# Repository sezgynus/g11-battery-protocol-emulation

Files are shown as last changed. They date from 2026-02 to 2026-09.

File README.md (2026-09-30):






# Language Selection
[English](README-en.md) | [Türkçe](README.md)

# G11 Battery Protocol Emulation

## Projeye Genel Bakış

Bu proje, Xiaomi G11 akıllı bataryası ile süpürge arasındaki kapalı haberleşme protokolünün tersine mühendislik yöntemiyle analiz edilmesini, protokolün çözümlenmesini ve ESP32 üzerinde emüle edilmesini kapsar.

Amaç yalnızca veri hattını dinlemek değil; fiziksel katmandan paket yapısına, adresleme ve checksum mekanizmasından işlevsel payload alanlarına kadar sistemi yeniden uygulanabilecek seviyede karakterize etmekti. Elde edilen protokol ESP32 üzerinde uygulanmış ve orijinal süpürge elektroniği tarafından kabul edilen çalışan bir emülatör ile doğrulanmıştır.

### Sonuç

- Kapalı batarya haberleşme arayüzü elektriksel olarak karakterize edildi.
- Fiziksel katman **single-wire, half-duplex, inverted UART** olarak belirlendi.
- Haberleşme **9600 baud, 8N1** olarak çözüldü.
- Süpürgenin master/polling, bataryanın slave/response tarafı olduğu doğrulandı.
- Paket sınırları, source/target adresleme yapısı ve 16-bit toplamsal checksum çözüldü.
- Checksum algoritması yaklaşık **6500 paketlik** veri setinin tamamında doğrulandı.
- Üç temel paket tipinde toplam **29 / 37 byte (~%78)** karakterize edildi.
- Emülasyon için gerekli işlevsel alanlar belirlendi ve ESP32 tabanlı protokol emülatörü başarıyla çalıştırıldı.
- Batarya denetleyici donanımı ve fiziksel batarya kutusu tasarlandı.

## Protokole Hızlı Bakış

| Özellik | Sonuç |
|---|---|
| Topoloji | Single-wire |
| Duplex | Half-duplex |
| Kodlama | Inverted UART |
| UART | 9600 baud, 8N1 |
| Master | Süpürge |
| Slave | Batarya |
| Hat genliği | ~24–25 V |
| Süpürge → Batarya | 0xFB → 0xFC |
| Batarya → Süpürge | 0xFC → 0xFB |
| Veri bütünlüğü | 16-bit toplamsal checksum |
| Karakterize edilen alan | 29 / 37 byte (~%78) |
| Emülasyon platformu | ESP32 |

```text
Start | Source ID | Target ID | Payload ... | Checksum_L | Checksum_H | End
```

```text
checksum = SUM(data bytes) & 0xFFFF
```

Checksum; başlangıç/bitiş byte'ları ve checksum alanının kendisi hariç paket byte'larının toplamıdır ve little-endian olarak `Checksum_L`, `Checksum_H` sırasıyla taşınır.

### Bulguların Güven Düzeyi

| Düzey | Alanlar |
|---|---|
| Doğrulanmış | Paket sınırları, source/target ID, checksum, batarya seviyesi, şarj durumu, tetik durumu, motor aktif/deaktif durumu |
| Güçlü biçimde desteklenen | Güç tüketimi, motor komut hızı |
| Kısmen karakterize | Akım alanı; davranış korelasyonu güçlü ancak birimi kesin değil |
| Bilinmeyen | Testlerde değişmeyen veya emülasyon için gerekli olmayan payload byte'ları |

> Payload coverage byte sayısı üzerinden hesaplanmıştır. Bilinmeyen alanlara rağmen, gösterilen batarya emülasyonu için gerekli alanlar belirlenmiştir.

## Tersine Mühendislik Akışı

```text
Konnektör ve pin tespiti
        ↓
Elektriksel karakterizasyon
        ↓
Güvenli sinyal yakalama
        ↓
Fiziksel katman tespiti
        ↓
Paket sınırları ve adresleme
        ↓
Checksum doğrulama
        ↓
Kontrollü kullanım senaryosu
        ↓
Payload korelasyonu
        ↓
ESP32 protokol emülasyonu
```

Aşağıdaki bölümler sonuçlara hangi ölçüm, hipotez ve doğrulama adımlarıyla ulaşıldığını gösterir.

## Reverse Engineering Metodolojisi

Bu proje aşağıdaki deterministik mühendislik adımlarını takip etmiştir:

<details>
<summary><strong>1️⃣ Arayüz Karakterizasyonu</strong></summary>

Batarya paketi ve süpürge gövdesi açılmadan analiz yapılması hedeflenmiştir.
Bu nedenle konnektör pin fonksiyonları dolaylı ve müdahalesiz (non-invasive) yöntemlerle
tespit edilmiştir.

## Referans PCB Görselleri

Model yeni olduğu için teardown materyali sınırlıdır.

Yapılan araştırmalar sonucunda:

- Batarya PCB görüntüsüne bir video incelemesinde,
- Süpürge tarafındaki PCB görüntüsüne çevrim içi bir yedek parça platformunda

ulaşılmıştır.

> Batarya PCB’sinde pin fonksiyonlarına dair işaretleme bulunmamaktadır.  
> Süpürge tarafındaki PCB üzerinde konnektör pin isimleri etiketlenmiştir.

📌 Referans Görseller:

### Batarya PCB fotoğrafı

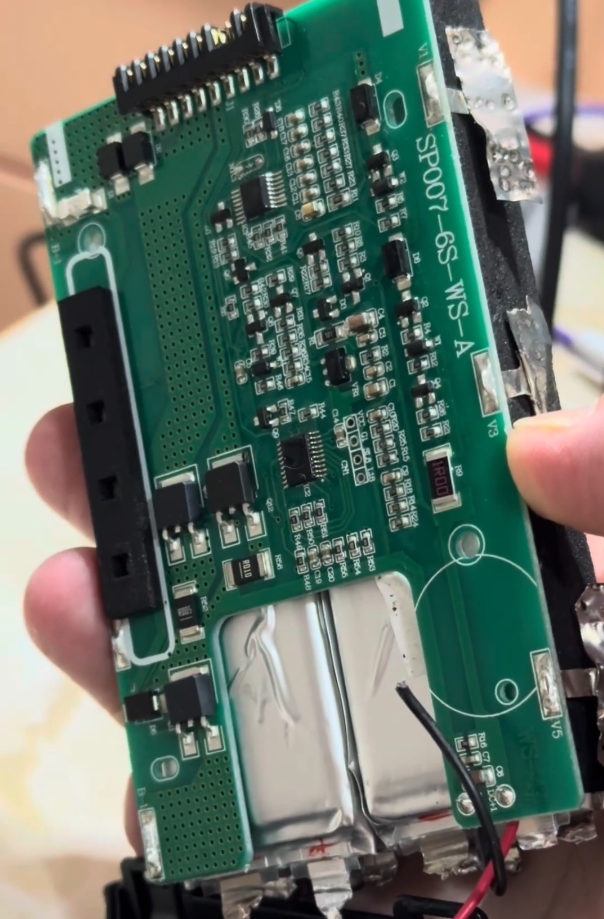
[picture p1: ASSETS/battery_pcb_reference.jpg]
Battery PCB Reference


### Süpürge PCB fotoğrafı

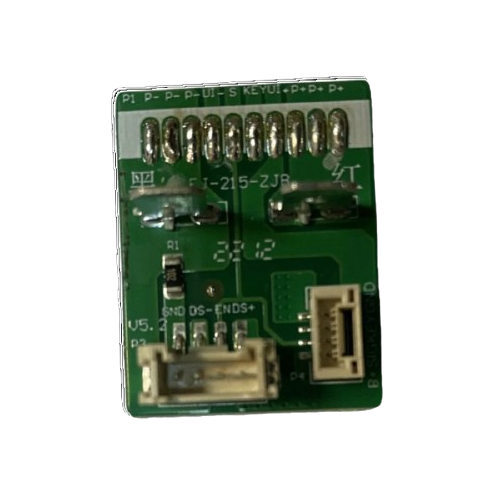
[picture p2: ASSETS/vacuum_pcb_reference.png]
Vacuum PCB Reference


---

## Konnektör Pin Dizilimi

10 pinli konnektör üzerinde yer alan pin isimleri:

P- | P- | P- | UI- | S | KEY | UI+ | P+ | P+ | P+

Ancak ilgili PCB'nin birebir aynı revizyona ait olduğu kesin olmadığı için
tüm pin fonksiyonları elektronik olarak doğrulanmıştır.

---

## Elektriksel Doğrulama

Batarya ve süpürge konnektörleri jumper kablolar ile açığa alınmış,
cihaz çalışırken ölçümler gerçekleştirilmiştir.

### Güç Hatları

- P- / P+ → Sürekli 24–25V DC  
  → Ana güç hattı olarak doğrulanmıştır.

### UI Hatları

- UI- / UI+ → Yalnızca ekran aktifken 24–25V  
  → Ekran besleme hattı olarak değerlendirilmiştir.

### KEY Hattı

- Tetik basılı → 24–25V  
- Tetik bırakıldığında → 0V  

→ Kullanıcı giriş hattı doğrulanmıştır.

### S Hattı

- Cihaz çalışırken → 24–25V genliğinde periyodik kare dalgalar  
- Cihaz kapalıyken → 0V sabit  

Bu davranış, hattın haberleşme hattı olduğunu güçlü şekilde göstermektedir.

---

### Pin Eşlemesinin Etiketlenmesi

Daha sonraki analiz çalışmalarında bağlantı hatalarını önlemek ve ölçüm
tekrar edilebilirliğini sağlamak amacıyla tespit edilen pin eşlemesi,
hem batarya hem de süpürge konnektörü üzerinde fiziksel olarak etiketlenmiştir.

Bu sayede:

- Ölçüm noktaları standardize edilmiştir.
- Yanlış bağlantı riski minimize edilmiştir.
- Veri yakalama aşamasında referans karışıklığı önlenmiştir.

### Etiketlenmiş Konnektör Görselleri

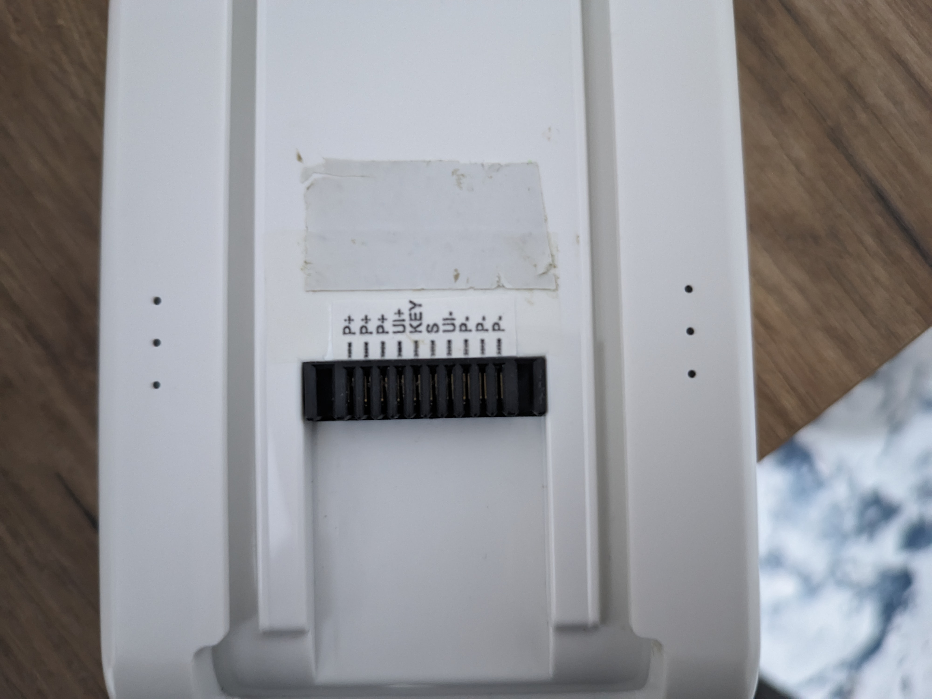
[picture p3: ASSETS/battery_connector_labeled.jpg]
Battery Connector Labeling
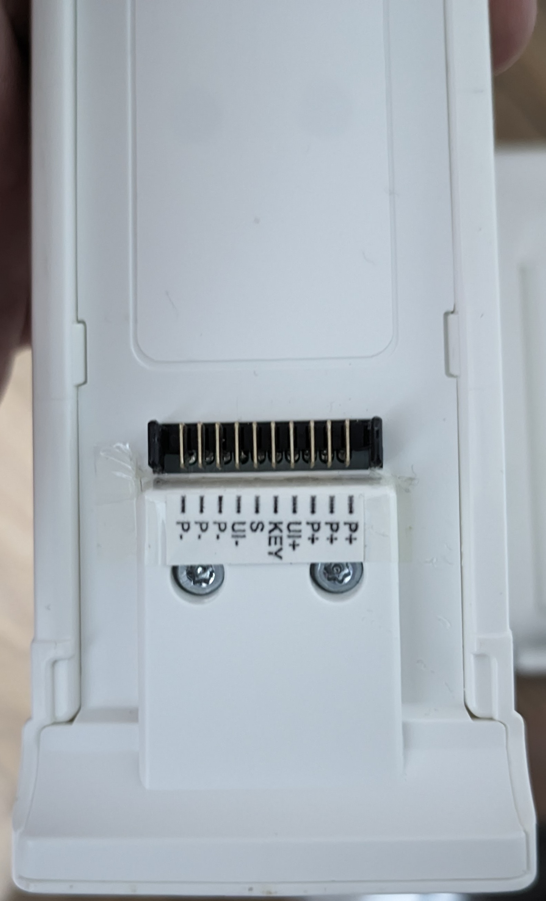
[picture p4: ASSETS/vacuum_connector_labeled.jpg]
Vacuum Connector Labeling
 

---

## Sonuç

- Güç hatları ayrıştırılmıştır.
- Kullanıcı giriş hattı doğrulanmıştır.
- Haberleşme hattı tespit edilmiştir.
- Sinyal genliği ~24–25V olarak ölçülmüştür.

Logic seviyesi 24V olduğu için doğrudan logic analyzer bağlantısı mümkün değildir.
Bir sonraki aşamada uygun level shifting çözümü gereklidir.
</details>
<details>
<summary><strong>2️⃣ Veri Yakalama ve Protokol Keşfi Denemeleri</strong></summary>

### Seviye Dönüştürücü (Level Shifter) Görselleri

#### 1. Delikli Pertinaks Üzerinde Yapılmış Devre
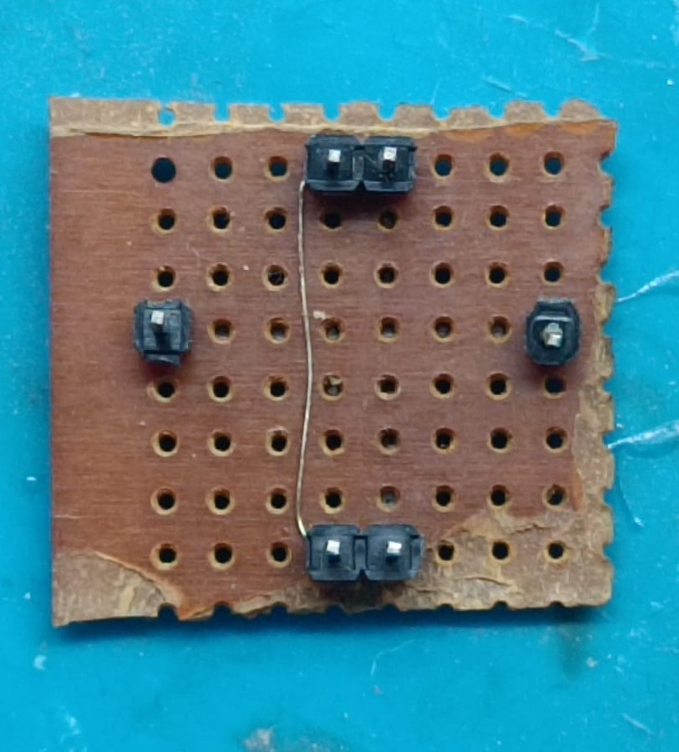
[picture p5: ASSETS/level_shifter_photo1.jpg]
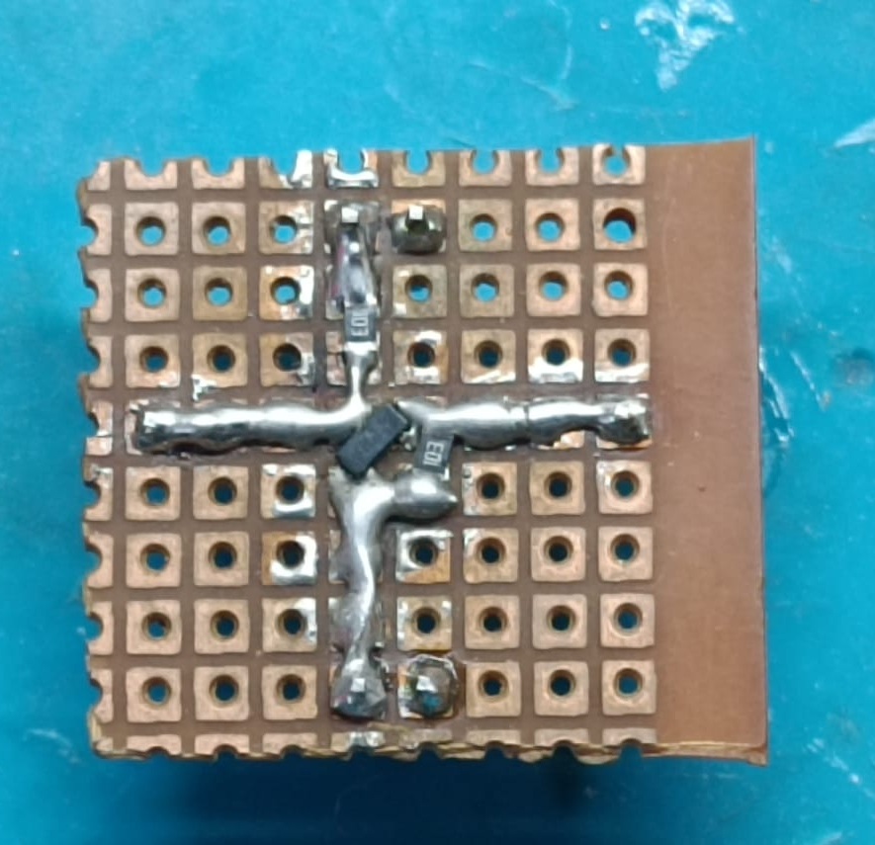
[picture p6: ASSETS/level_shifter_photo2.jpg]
 

#### 2. Şematik Görseli
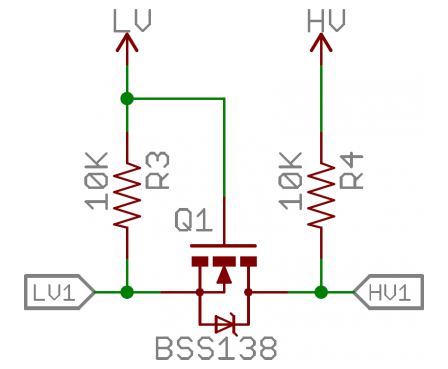
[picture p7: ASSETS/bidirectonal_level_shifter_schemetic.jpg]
Level Shifter Schematic


Batarya konnektörü ve level shifter devresi kurulduktan sonra
S hattından jumper alınıp lojik analizör girişine bağlanmıştır.  
Hattın güvenli şekilde dinlenmesi sağlanmıştır.

---

## İlk Analiz: 1-Wire Hipotezi

Hattın tek hatlı olması nedeniyle ilk olarak **1-Wire protokolü** varsayılmıştır.  

- Bazı anlamlı byte'lar gözlemlense de  
- Çok sayıda framing hatası ve korelasyonsuz byte dizileri mevcuttu  

Veri kaydı ve ekran görüntüleri:

[Capture Dosyası (Session 0.sal)](DOCUMENT/Session%200.sal)

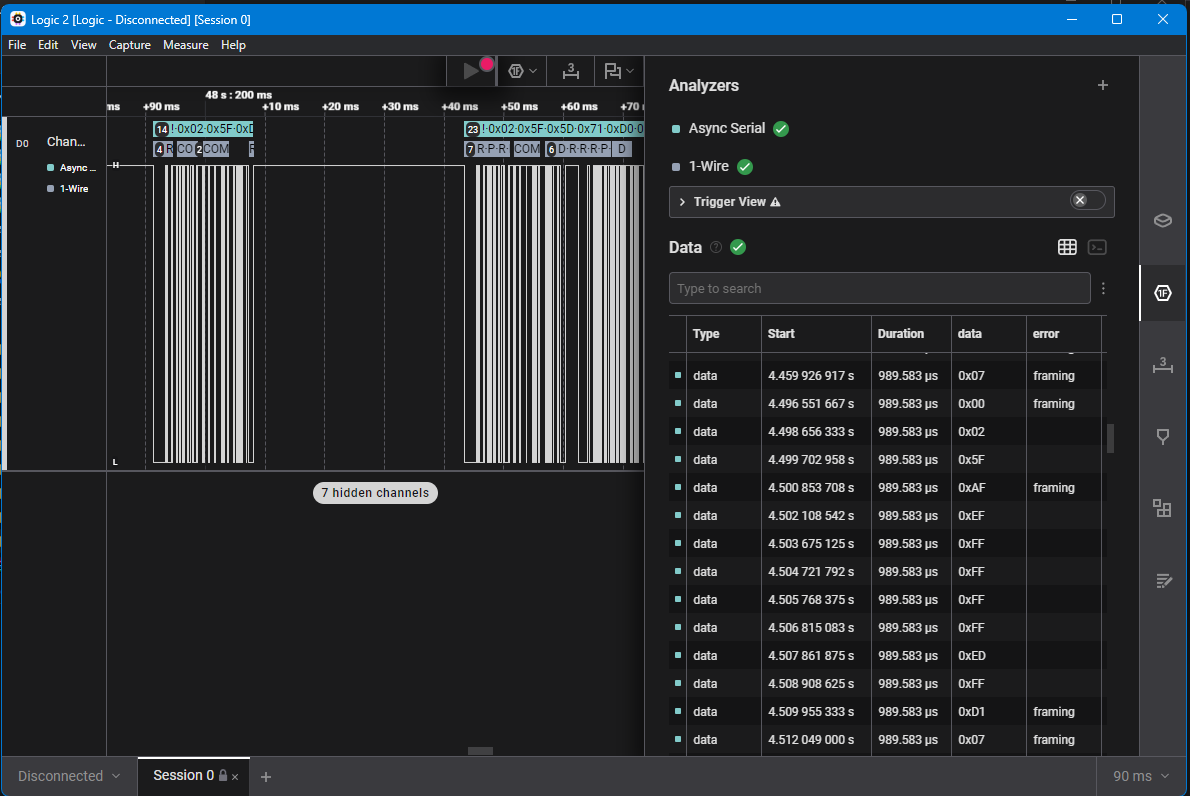
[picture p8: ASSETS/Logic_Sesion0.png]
Logic Analyzer Capture


Bu gözlemler, hattın **standart 1-Wire protokolü olmadığı** ihtimalini güçlendirdi.

---

## İkinci Analiz: Half-Duplex Single-Wire UART Hipotezi

Daha sonra hattın **half-duplex single-wire UART** olabileceği üzerine yoğunlaşıldı.  

- En yaygın standart baud hızlarında sinyal analiz edildi  
- Hâlâ çok sayıda çerçeveleme (framing) hatası vardı ve korelasyon gözlemlenmedi  

---

## Çözüm: Sinyalin Terslenmesi ve Doğru Parametreler

Son bir deneme olarak sinyal terslenerek analiz edildi ve:

- **8N1 standardı**  
- **9600 baud**  
- **Inverted signal**

parametreleriyle **çerçeveler (frame) tam olarak oturdu**.  

Veri kaydı ve ekran görüntüleri:

[Capture Dosyası (Session 1.sal)](DOCUMENT/Session%201.sal)  

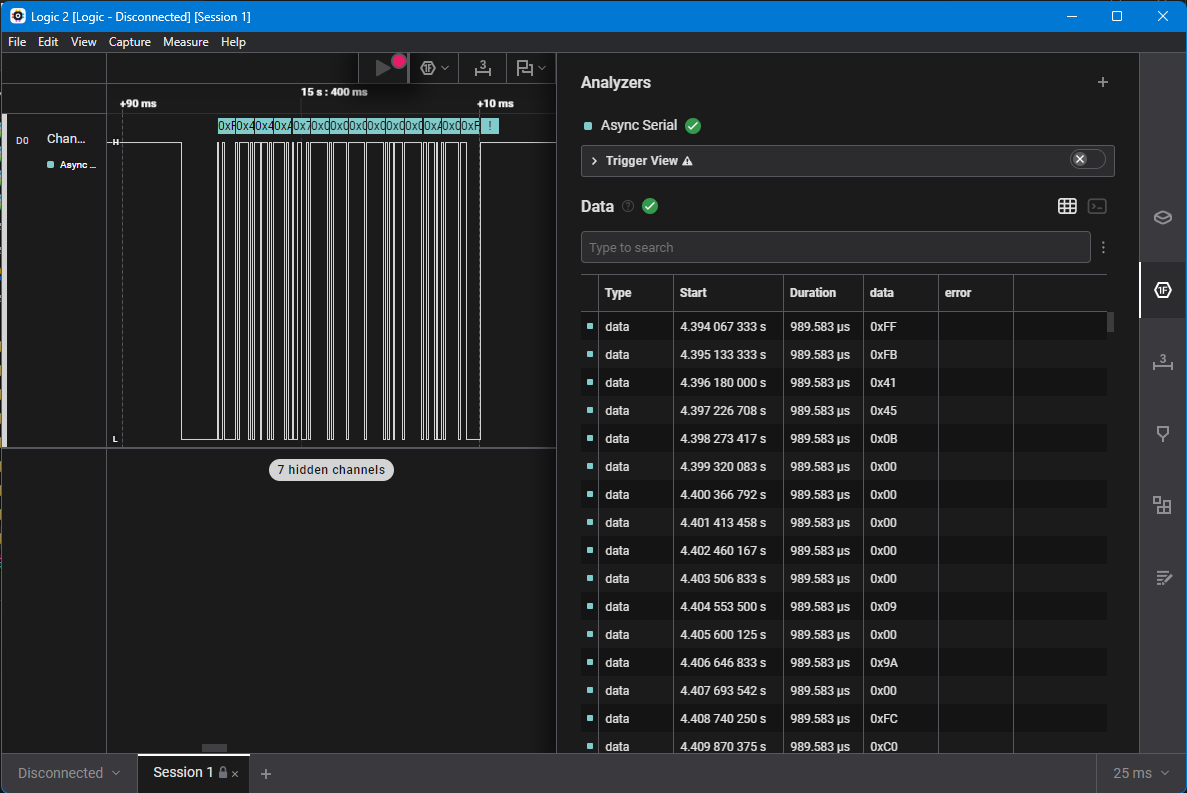
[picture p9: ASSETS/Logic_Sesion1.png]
Logic Analyzer Capture
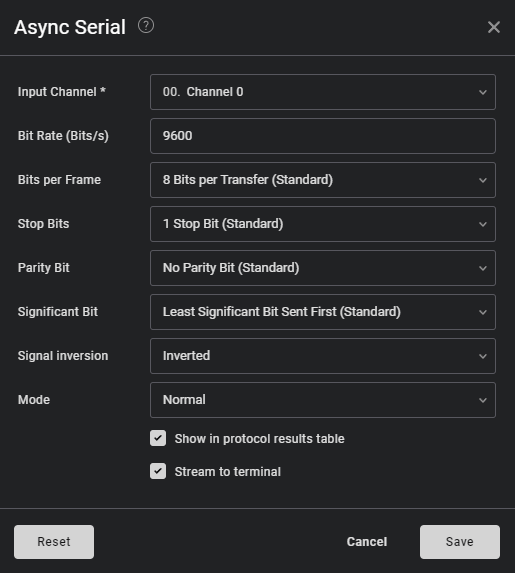
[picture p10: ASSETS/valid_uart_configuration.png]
Protocol Analyzer Konfigürasyonu
 

Byte dizileri artık **istikrarlı ve tekrar eden korelasyonlar** göstermeye başladı.  

## Master/Slave Tespiti

Bit çerçeveleri doğru şekilde yakalandıktan sonra, byte seviyesinde analiz ve
paket çözümlemesi için hangi tarafın master (sorgulayan) ve hangi tarafın
slave (cevaplayan) olduğunu belirlemek gerekiyordu.

Protokol tek hatlı olduğundan:

- Bir taraf sürekli dinlemede kalıyor  
- Diğer taraf sorgulama (polling) yapıyor  

Hangi tarafın master olduğunu anlamak için:

1. Haberleşme hattı geçici olarak kesildi  
2. Süpürge çalıştırıldı  
3. İlk konuşma denemesi her iki taraftan ayrı ayrı dinlendi  

### Sonuç

- **Master / Polling yapan taraf:** Süpürge  
- **Slave / Cevap veren taraf:** Batarya

Bu tespit, veri setinin doğru şekilde analiz edilmesini ve
sonraki aşama olan **alan tespiti (field identification)** için sağlam bir temel sağlamıştır.

## Paket Başlangıç ve Bitiş Koşulları

Lojik analizör ile alınan byte akışı incelendiğinde, tekrarlayan bir örüntü gözlemlenmiştir:

- **0xFB** → Paket başlangıcı  
- **0xFC** → Paket sonu  

Dikkat çekici nokta:  
- 0xFB’den sonra 12 byte ileride 0xFC  
- 0xFC’den sonra 8 veya 9 byte sonra tekrar 0xFB  

Bu örüntülerin paket başlangıç ve bitiş sınırlarını temsil ettiği varsayılmıştır.

---

## Excel Tablosuna Aktarım

Bu paket başlangıç/bitiş koşullarına göre, örnek bir konuşma akışı:

- Her 0xFB…0xFC paketi → Süpürgeden bataryaya  
- Her 0xFC…0xFB paketi → Bataryadan süpürgeye

Bu paketler **satırlara ayrılarak Excel tablosuna** aktarıldı.  
Henüz her byte’ın anlamını bilmiyor olsak da, tekrarlı alanlar gözlemlenebiliyordu.

- **Sarı arka planlı satırlar** → Süpürgeden bataryaya giden paketler  
- **Mavi arka planlı satırlar** → Bataryadan süpürgeye giden paketler

### Örnek [Excel](DOCUMENT/G11_protocol_analyze.xlsx) Görseli

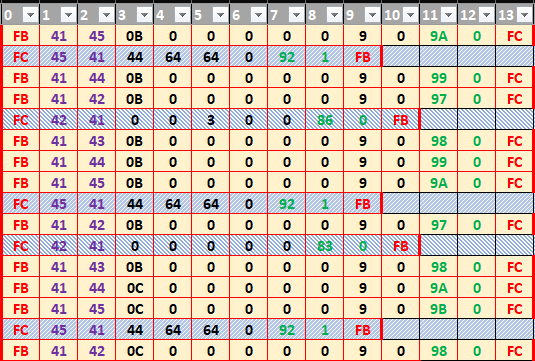
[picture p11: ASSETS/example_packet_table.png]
Excel Paket Tablosu Örneği


## Paket İçi Korelasyon ve İlk Byte Analizi

Excel tablosunu dikkatle incelediğimizde bazı anlamlı korelasyonlar ortaya çıkmıştır:

Örnek bir süpürge → batarya paketi:

| Byte # |0 | 1 | 2  | 3  | 4 | 5| 6 | 7 | 8 | 9 | 10 | 11 | 12 | 13 |
|---|-----|-----|----|---|---|---|---|---|---|----|----|----|----|----|
| Paket  | FB  | 41  | 45 | 0B| 00| 00| 00| 00| 00| 09 | 00 | 9A | 00 | FC |

Karşılık gelen batarya → süpürge paketi:

| Byte # |0 | 1 | 2 | 3  | 4  | 5  | 6  | 7  | 8  | 9  | 10 | 11 | 12 | 13 |
|---|-----|-----|----|----|----|----|----|----|----|----|----|----|----|----|
| Paket  | FC  | 45  | 41 | 44 | 64 | 64 | 00 | 92 | 01 | FB | | | | |

### İlk Korelasyon Çıkarımı

- **Byte 1 (0x41)** → Kaynak ID (source ID)  
- **Byte 2 (0x45)** → Hedef ID (destination ID)  

Önce süpürgeden gelen pakette, ardından bataryadan gelen pakette bu değerlerin karşılıklı olarak eşleştiği gözlemlenmiştir.  

Bu korelasyon, **master/slave ve adresleme mekanizması** hakkında ilk ipuçlarını vermektedir.

### Checksum / Veri Bütünlüğü Doğrulama

İstisnasız her pakette geçerli olan **source/target ID korelasyonu** sayesinde
çözümlenmesi gereken **son 2 byte alanı** daha anlamlı hale gelmiştir.  

Çoğu seri haberleşme protokolünde olduğu gibi, G11 batarya protokolünde de
**checksum veya CRC benzeri bir veri bütünlüğü doğrulama alanı** vardır.

#### İlk Varsayım

- Her paketin **son 2 byte’ı** checksum alanı olarak kabul edildi  
- Paket başlangıç ve bitiş byte'ları bu hesaba dahil edilmedi  
- Paket boyutu değişken olsa bile bu varsayım uygulanabilir

#### Doğrulama

- Seçilen örnek paketler üzerinde **checksum hesaplaması** yapıldı  
- Hesaplama yöntemi:  checksum = SUM(paket başlangıç/bitiş byte'ları ve checksum alanı hariç tüm byte'lar)
- Tüm test edilen paketlerde hesaplanan checksum ile paket içindeki son 2 byte **tam olarak eşleşti**  

#### Örnek Paket ve Checksum

| Paket (süpürge → batarya) | Byte 0 | Byte 1 | … | Byte n-2(Checksum_L) | Byte n-1(Checksum_H) | Byte n |
|---|---|---|---|---|---|---|
| Örnek 1 | 0xFB | 0x41 | … | 0x9A | 0x00 | 0xFC |

Hesaplanan Checksum        0x41+0x45+0x0B+0x09=0x009A

> Son 2 byte paket içindeki checksum ile tam olarak eşleşmektedir.

### Tüm Paketler Üzerinde Checksum Doğrulama

Tek paket üzerinden yapılan denemeler yeterli kanıt sağlamadığından,
checksum doğrulaması **tüm veri setine** uygulandı:

- Excel tablosunda, paket başlangıç ve bitiş byte'ları dikkate alınmadan
  her paketin son 2 byte’ının checksum olduğu varsayıldı  
- Paket içerisindeki **checksum alanı** ile **hesaplanan checksum** karşılaştırıldı  
- Bu karşılaştırmayı otomatik yapan **formüllü bir sütun** oluşturuldu

#### Sonuç

- Toplam ~6500 paket üzerinde doğrulama yapıldı  
- Tek bir paket bile formül doğrulamasını ihlal etmedi  

> Böylece checksum alanı, yaklaşık 6500 paketlik veri setinin tamamında doğrulanmıştır.

#### Checksum Hesaplama

Aşağıdaki formül, paket tipine göre hangi byte’ların checksum’a dahil edileceğini belirler ve checksum'u hesaplar:

```
=EĞER([@1]=41;
    DEC2HEX(TOPLA(HEX2DEC([@1]);HEX2DEC([@2]);HEX2DEC([@3]);HEX2DEC([@4]);HEX2DEC([@5]);HEX2DEC([@6]);HEX2DEC([@7]);HEX2DEC([@8]);HEX2DEC([@9]);HEX2DEC([@10]));4);
EĞER([@1]=45;
    DEC2HEX(TOPLA(HEX2DEC([@1]);HEX2DEC([@2]);HEX2DEC([@3]);HEX2DEC([@4]);HEX2DEC([@5]);HEX2DEC([@6]));4);
EĞER([@1]=42;
    DEC2HEX(TOPLA(HEX2DEC([@1]);HEX2DEC([@2]);HEX2DEC([@3]);HEX2DEC([@4]);HEX2DEC([@5]);HEX2DEC([@6]);HEX2DEC([@7]));4)
)))
```
**Checksum OK?** sütunundaki bu formül, hesaplanan checksum ile paketteki checksum alanını karşılaştırır ve sonuca göre OK veya ERROR döndürür.

```
=EĞER([@Checksum]=
EĞER([@1]=41;
  DEC2HEX(BİTVEYA(BİTSOLAKAYDIR(HEX2DEC([@12]);8);HEX2DEC([@11]));4);
EĞER([@1]=45;
  DEC2HEX(BİTVEYA(BİTSOLAKAYDIR(HEX2DEC([@8]);8);HEX2DEC([@7]));4);
EĞER([@1]=42;
  DEC2HEX(BİTVEYA(BİTSOLAKAYDIR(HEX2DEC([@9]);8);HEX2DEC([@8]));4);0
)));"OK";"ERROR")
```

#### Excel Checksum Alanı Doğrulama Görseli

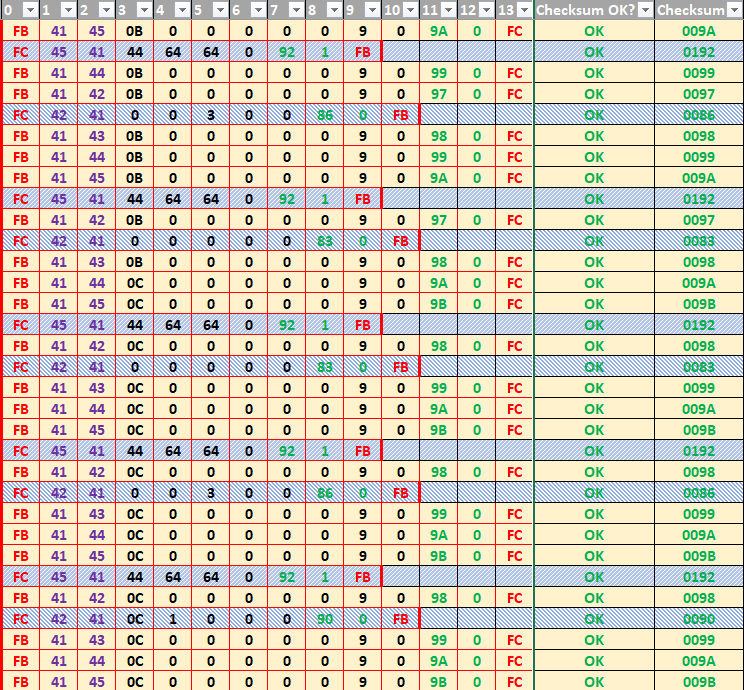
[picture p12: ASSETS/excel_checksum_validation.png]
Excel Checksum Validation

</details>
<details>
<summary><strong>3️⃣ Alan Tespiti (Payload Analizi)</strong></summary>

Payload içindeki alanları belirlemek için yaklaşık **4 dakikalık bir kullanım senaryosu** hazırlandı.  
Senaryoda hangi anda hangi işlemin yapıldığı tabloya döküldü:

| Zaman | Olay |
|---|---|
| 00:04:00 | Açılış |
| 00:07:00 | Mod Değişimi: AUTO → TURBO |
| 00:11:00 | Mod Değişimi: TURBO → ECO |
| 00:13:00 | Tetiğe basma – motoru çalıştırma (ECO) |
| 00:20:00 | Tetiği bırakma – motoru durdurma (ECO) |
| 00:21:00 | Tetiğe basma – motoru çalıştırma (ECO) |
| 00:27:00 | Tetiği bırakma – motoru durdurma (ECO) |
| 00:29:00 | Mod Değişimi: ECO → AUTO |
| 00:30:00 | Tetiğe basma – motoru çalıştırma (AUTO) |
| 00:36:00 | Tetiği bırakma – motoru durdurma (AUTO) |
| 00:38:00 | Tetiğe basma – motoru çalıştırma (AUTO) |
| 00:42:00 | Tetiği bırakma – motoru durdurma (AUTO) |
| 00:43:00 | Mod Değişimi: AUTO → TURBO |
| 00:45:00 | Tetiğe basma – motoru çalıştırma (TURBO) |
| 00:52:00 | Tetiği bırakma – motoru durdurma (TURBO) |
| 00:53:00 | Tetiğe basma – motoru çalıştırma (TURBO) |
| 01:04:00 | Tetiği bırakma – motoru durdurma (TURBO) |
| 01:05:00 | Tetik kilidi aktif |
| 01:08:00 | Tetiğe basma – motoru çalıştırma (TURBO) |
| 01:08:00 | Tetiği bırakma |
| 01:15:00 | Vakumu tıkama |
| 01:16:00 | Vakumu açma |
| 01:17:00 | Vakumu tıkama |
| 01:18:00 | Vakumu açma |
| 03:03:00 | Tetiğe basma – motoru durdurma (TURBO) |
| 03:04:00 | Tetiği bırakma |
| 03:06:00 | Tetiğe basma – motoru çalıştırma (TURBO) |
| 03:06:00 | Tetiği bırakma |
| 03:25:00 | Mod Değişimi: TURBO → ECO |
| 03:29:00 | Mod Değişimi: ECO → AUTO |
| 03:31:00 | Mod Değişimi: AUTO → TURBO |
| 03:34:00 | Mod Değişimi: TURBO → ECO |
| 03:40:00 | Tetiğe basma – motoru durdurma (TURBO) |
| 03:40:00 | Tetiği bırakma |
| 03:47:00 | Şarj aleti takma (%63) |
| 03:52:00 | Şarj aleti çıkarma (%63) |
| 03:56:00 | SON |

---

## Payload Korelasyonu ve Batarya Seviyesi

> **Not:** Bu dokümanda byte ve bit indeksleri 0'dan başlamaktadır.

- Kullanım senaryosu sırasında **lojik analizör** ile eş zamanlı olarak veri kaydedildi.  
- Excel tablosuna paketler aktarıldı, önceki formüller ve sütunlar kullanıldı.  
- Süpürgenin ekranında **batarya şarj seviyesi** canlı olarak gösteriliyor, dolayısıyla bataryadan gelen paketlerde bir **Batarya Seviyesi (Battery Level)** alanı olması gerektiği varsayıldı.  

### Batarya Seviyesi (Battery Level) Alanının Tespiti

- Bataryadan süpürgeye gönderilen paketler (0xFC ile başlar, 0xFB ile biter) filtrelendi.  
- Kaynak ID’si **0x45** olan paketlerin **Byte 4** zamanla düşen bir eğilim gösterdi:  
  - Başlangıçta ondalık olarak 100  
  - Kullanım senaryosunun sonunda ondalık olarak 63  
- Bu byte **Batarya Seviyesi (Battery Level, %)** olarak işaretlendi.  

#### Excel Formülü ve Görsel

- Tüm paketlerde Byte 4 üzerinden **Batarya Seviyesi** hesaplayan bir sütun eklendi.  
- Zaman ekseninde grafiği çizildi:

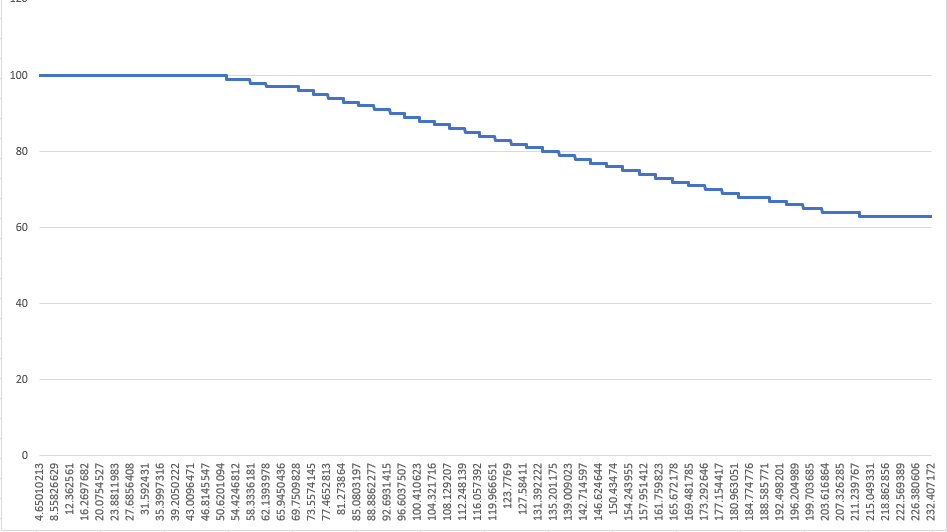
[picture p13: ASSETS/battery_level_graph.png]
Battery Level Over Time


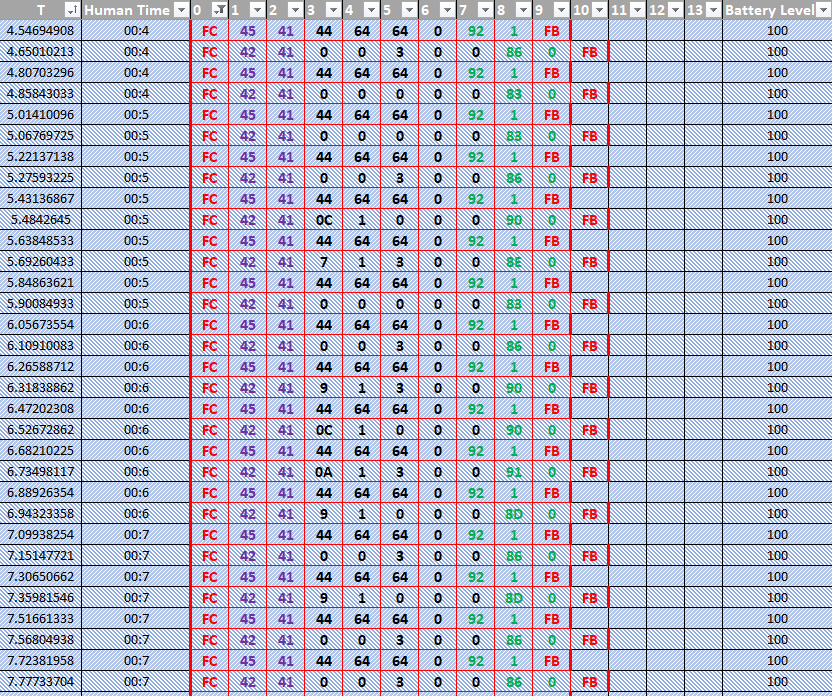
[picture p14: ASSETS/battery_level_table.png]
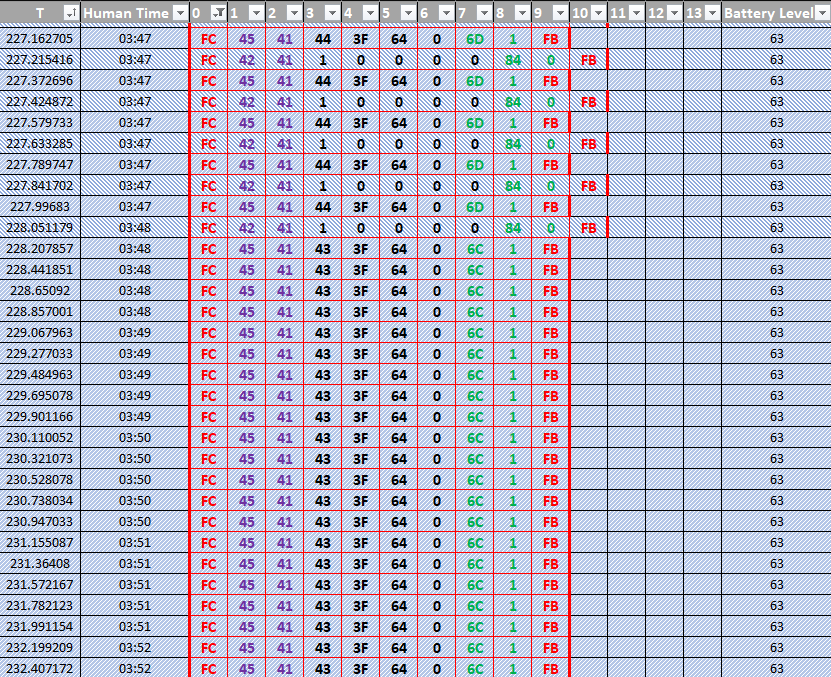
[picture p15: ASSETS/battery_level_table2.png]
 

### Şarj Durumu (Charger Status) Alanının Tespiti

Batarya tarafında alınması gereken bir diğer veri **şarj aleti takılma durumu**dur.  
- Süpürge ekranında anlık olarak gösterildiği için bataryadan gelen paketlerde bu bilgiyi içeren bir alan olmalıydı.  
- Kullanım senaryosunda şarj aleti takma/çıkarma anlarına karşılık gelen **byte ve bit** arandı:  
  - Kaynak ID: **0x45**  
  - Byte: **Byte 3**  
  - Bit: **Bit 3**  

Bu bitin durumu **1 → şarj aleti takılı**, **0 → şarj aleti çıkarıldı** olarak değerlendirildi.  

- Excel tablosuna yeni bir sütun eklenerek tüm paketler için bu bitin durumu hesaplandı.  
- Sonuçlar kullanım senaryosundaki olaylarla birebir uyumlu çıktı.  

#### Charger Status Görseli

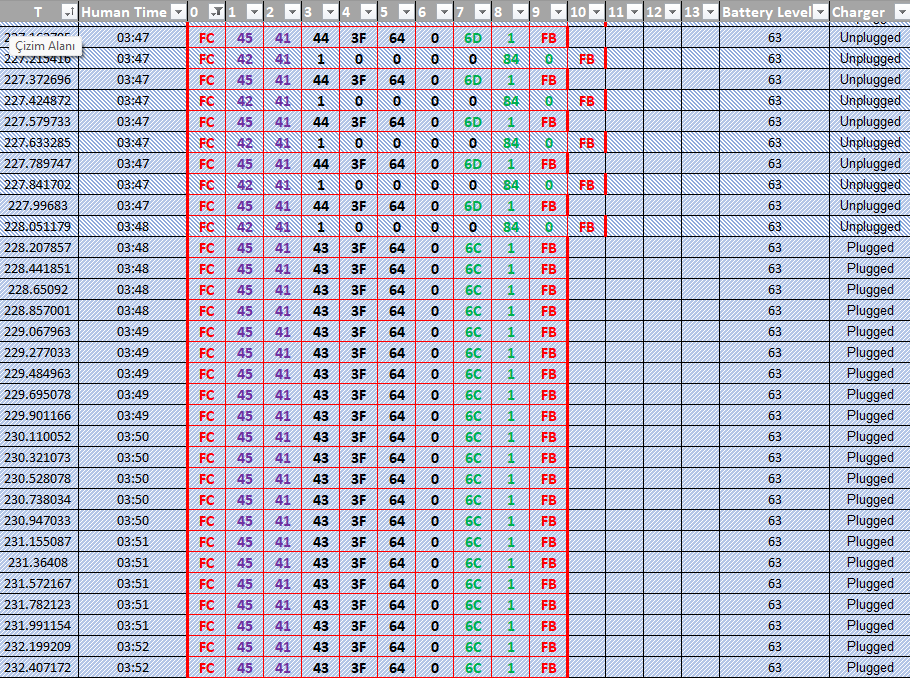
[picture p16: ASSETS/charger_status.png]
Charger Status Column in Excel


### Güç Modu ve Motor Gücü Alanı Analizi

Kullanım senaryosunda süpürge, kasıtlı olarak **güç modları arasında geçişler** yaptı, durdurulup tekrar çalıştırıldı ve bazı anlarda tıkama ile kısa süreli zorlandı.  
Amaç: protokoldeki aynı ana denk gelen paketlerdeki değişimleri analiz etmek.

- Süpürge **3 güç kademesi** içeriyor: düşük → orta → yüksek  
- Mod değişimlerinde **motor devri, motor voltajı ve akım**da değişim bekleniyor  

#### 0x45 Kaynak ID’li Paket

- Bu pakette henüz anlamlandırılamayan **2 byte** bulunmaktadır. Bu alanların BMS hata veya durum bayrakları olduğu düşünülmektedir. Kullanılan batarya sağlıklı olduğundan ilgili hata durumları oluşturulamadı ve bu alanlar mevcut analiz kapsamında incelenmedi.

#### 0x42 Kaynak ID’li Paket

- Henüz keşfedilmeyi bekleyen **5 byte’lık payload alanı** mevcut  
- Analiz için **Byte 3 ve Byte 4 birleştirilerek 16-bit sayısal bir değer** hesaplandı  
- Tüm 0x42 paketleri filtrelendi ve Excel tablosuna eklenerek çizgi grafiği oluşturuldu  

#### Sonuç

- Grafikte yaklaşık **45. saniyede 500 değerine ulaşan pikler** gözlendi  
- Öncesi ve sonrası, süpürge çalıştırma/durdurma ve tıkama anındaki dalgalanmalarla uyumlu  
- Cihazın teknik özelliklerine göre süpürgenin **500 W gücünde** olduğu biliniyor  
- Tüm bu bulgular, söz konusu **16-bit alanın watt cinsinden güç tüketimini** temsil ettiğini güçlü biçimde desteklemektedir  

### Güç Tüketimi Grafiği

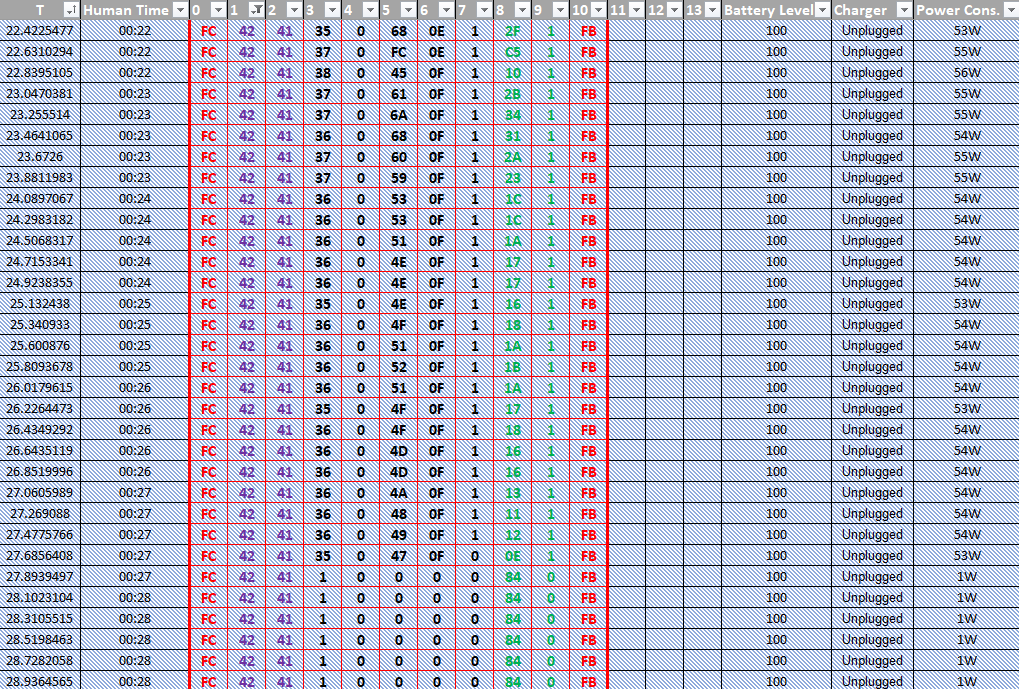
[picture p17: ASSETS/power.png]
Power Consumption Table
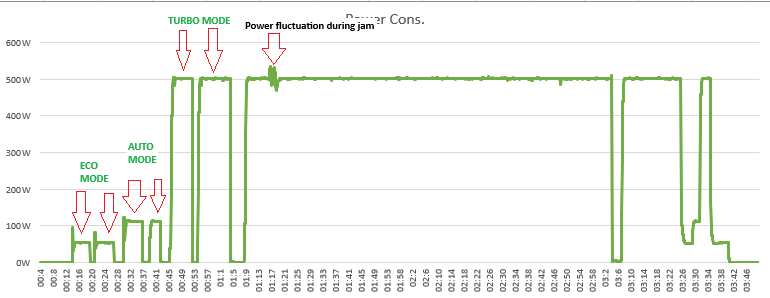
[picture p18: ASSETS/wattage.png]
Power Consumption Graph
 

### Akım (Current) Alanının Tespiti

- 0x42 kaynak ID’li paketlerdeki Byte 5 ve Byte 6 birleştirilerek 16-bit’lik bir sütun oluşturuldu.  
- Bu sütunun çizgi grafiği çıkarıldı ve analiz edildi.

Grafiğe bakıldığında:  

- Tıkama anında bariz pikler gözlemlendi
- Bir elektrik motorunun davranışına göre mantıklı: motor zorlandığında çektiği akım artar.  
- Bu durum grafikte açıkça gözleniyor.  
- Değerler cihazın nominal gücüyle kıyaslandığında biraz düşük görünüyor, bu nedenle birim kesin değil; Bu değer ham bir ADC verisi olabilir. Alternatif olarak motor tahmin edilenden daha yüksek bir gerilimde çalışıyorsa değerlerin amper cinsinden olması mümkün olabilir.  
- Tıkama ve mod geçişleri sırasında gözlenen örüntüler bu yorumla uyumludur; bu nedenle alan **akım (current)** verisi olarak değerlendirilmiştir.

### Akım Grafiği

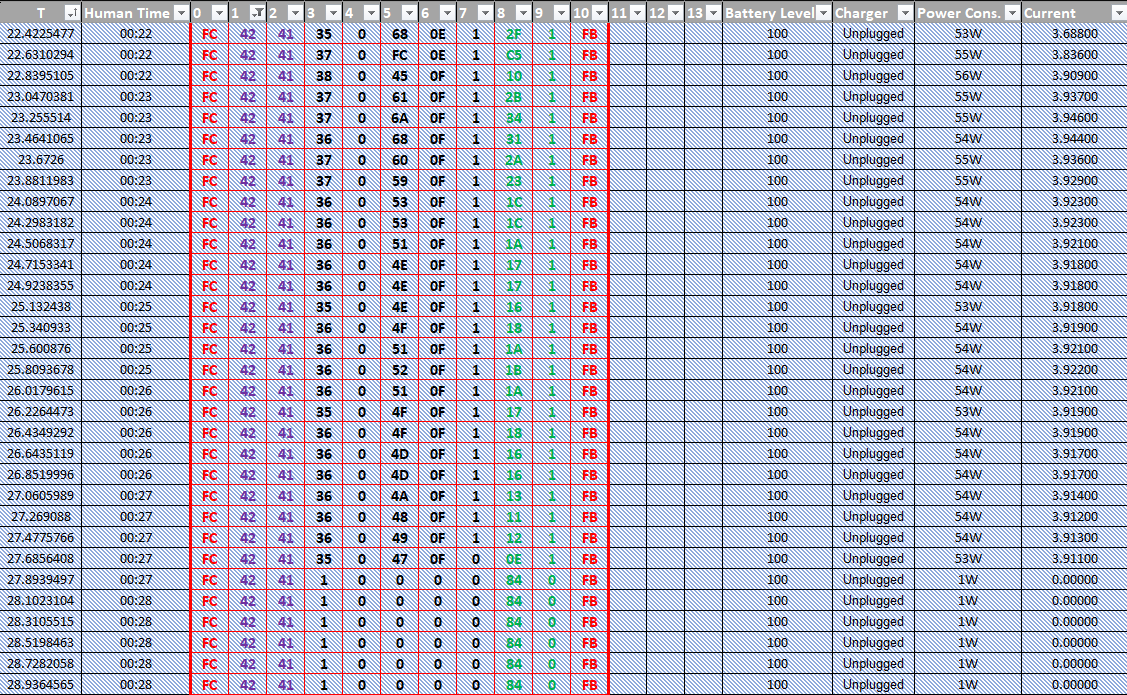
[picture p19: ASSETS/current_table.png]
Current Table
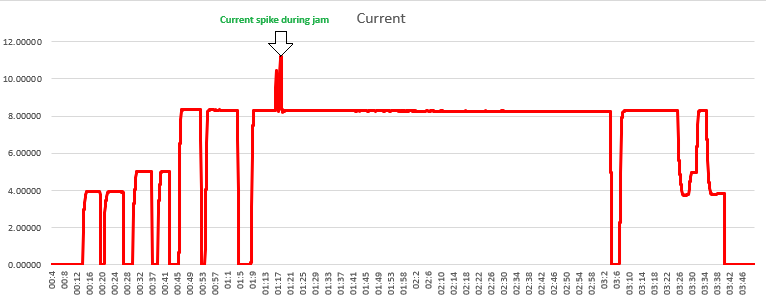
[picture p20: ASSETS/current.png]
Current Graph
 

### Voltaj (Voltage) Türetimi ve Akım Alanının Doğrulanması

Akım ve güç verilerini daha iyi anlamak ve akım alanındaki tespitimizi desteklemek için:

- Türetilmiş bir **voltaj sütunu** oluşturuldu:  
  - Formül: \( P = V × I \)  
  - Güç sütunları, akım (varsayılan) sütunlarına bölünerek hesaplandı.
- Oluşturulan voltaj sütununun çizgi grafiği çıkarıldı.

Grafik analizinde:

- **Tıkama anında voltaj düşümleri** gözlemlendi → elektrik motorlarının yük altında voltaj düşmesi beklenen bir davranış.
- **Motorun sıfır hızdan kalkış anlarında voltaj peakleri** mantıklı ve elektrik motorlarının karakteristiği ile uyumlu.
- Bu gözlemler, daha önce belirlenen **akım ve güç alanlarının kendi içinde tutarlı olduğunu** destekliyor.
- Bu sonuçlar, akım alanına ilişkin çıkarımı destekleyen ek kanıt sağlamıştır.

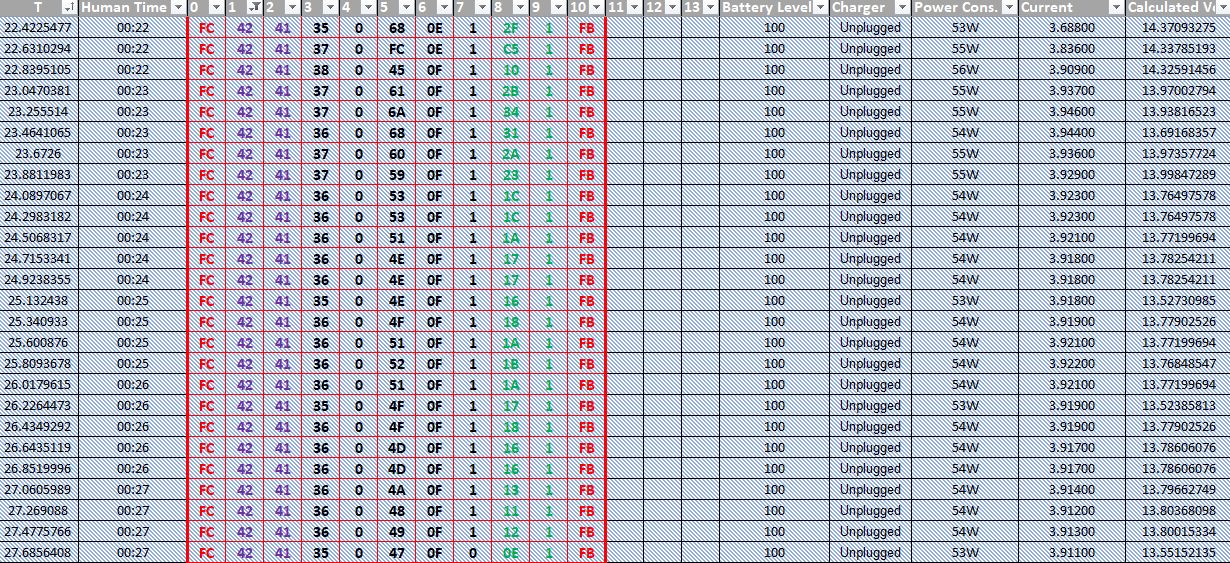
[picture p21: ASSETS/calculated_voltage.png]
Voltage Table
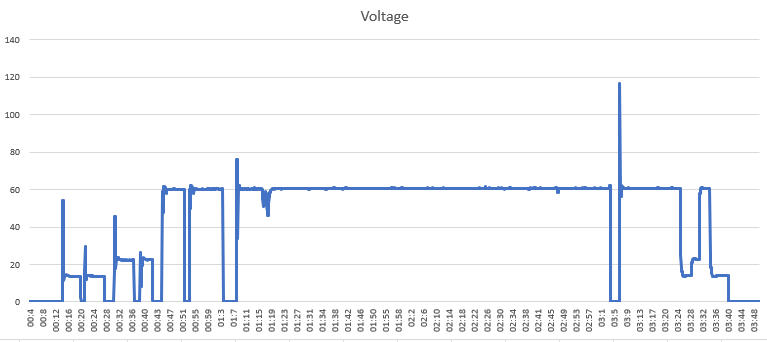
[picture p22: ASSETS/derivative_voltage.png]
Voltage Graph
 

### Motor Aktif/Deaktif Durumu (Motor Status)

0x42 kaynak ID'li paket üzerinde **yalnızca Byte 7** tespit edilememişti.  

- Bu byte incelendiğinde:
  - Motor çalışırken → 1  
  - Motor dururken → 0  

- Gözlemlerde bu davranış tüm kullanım senaryosu boyunca tutarlıydı.  
- Bu nedenle, **grafik oluşturmaya gerek kalmadan** bu byte doğrudan **Motor Aktif/Deaktif (Motor Status)** olarak işaretlendi.

## Süpürge Paketleri: 0x41 Kaynak ID

Süpürgeden gelen **tek paket tipi** 0x41 kaynak ID’li paket incelenmiştir.  

- Tüm veri seti boyunca değişen alanlar: Byte 3, Byte 4, Byte 5 ve Byte 6.

      Byte 6 yalnızca 0 ve 1 değerlerini alabildiği için başlangıçta sonraki analize bırakılmıştır.

### Byte 3, Byte 4 ve Byte 5 – Motor Devri / Komut Edilen Hız

- Byte 3, Byte 4 ve Byte 5 birleştirilerek 24 bitlik bir değer hesaplanmıştır.  
- Grafikte minimum: 0, maksimum: 128000 değerleri gözlemlenmiştir.  
- Akım ve güç grafiklerinde pattern ile uyum gözlemlenmiştir.

> Bu değerler, bu alanın motor devri olduğunu düşündürmüştür, çünkü 128000 RPM gibi bir değer bir vakum motoru için olması gereken yüksek devirdir.  
> Ancak grafiğin bu kadar stabil olması ve akım ile güç alanlarındaki dalgalanmaların görülmemesi, bunun bir **gerçek hız (actual velocity)** olmadığını, yalnızca **motor sürücüye gönderilen komut edilen hız (commanded velocity)** değeri olduğunu düşündürmektedir.

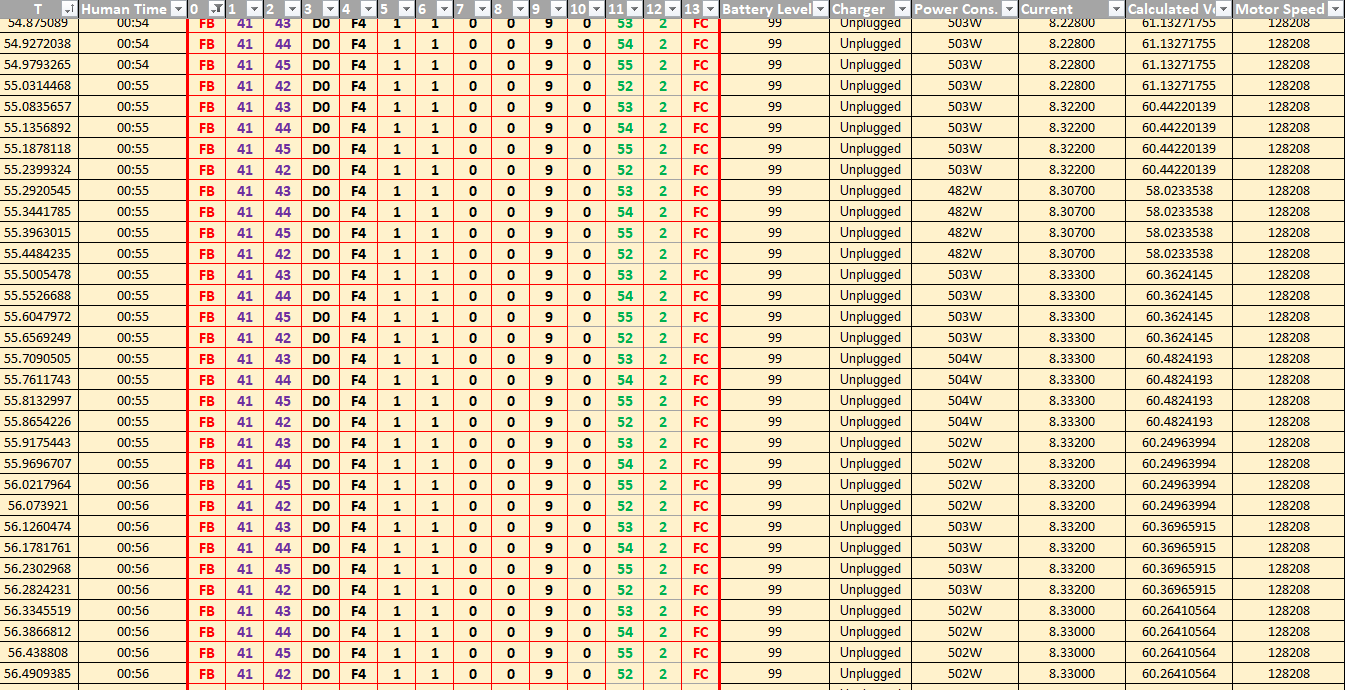
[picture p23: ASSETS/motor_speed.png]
Motor Commanded Velocity Graph
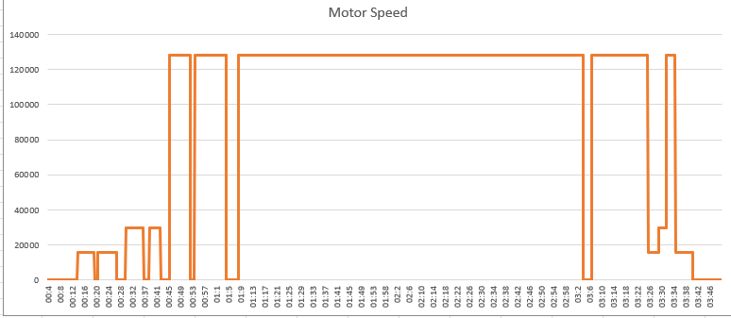
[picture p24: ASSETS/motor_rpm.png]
Motor Commanded Velocity Graph
 

#### Byte 6 – Tetik Durumu

- **Byte 6** tamamen **tetik basma / bırakma durumlarını** göstermektedir.  
  → 4 dakikalık kullanım senaryosunda tüm değişiklikler doğrulanmıştır.  

Diğer byte’larda kullanım senaryosu boyunca hiçbir değişiklik gözlemlenmemiştir.

---

</details>

## Protokol Referansı

Bu bölüm, tersine mühendislik sonunda elde edilen paket tanımlarını tek yerde toplar. Byte ve bit indeksleri 0'dan başlar.

### Sonuç: Çözülen Paketler ve Alanlar

#### 1️⃣ Süpürgeden Bataryaya Gönderilen Paket (0x41 Kaynak ID)

| Byte | Field | Açıklama |
|---|---|---|
| 0 | Packet Start | 0xFB |
| 1 | Source ID | 0x41 |
| 2 | Target ID | 0x42/0x43/0x44/0x45 |
| 3 | Motor Speed Low Byte | Motor devir değeri, 16–24 bit |
| 4 | Motor Speed Mid Byte | Motor devir değeri, 16–24 bit |
| 5 | Motor Speed High Byte | Motor devir değeri, 16–24 bit |
| 6 | Trigger Status | 0: Basılmamış, 1: Basılı |
| 7 | Unknown | Henüz çözülmedi |
| 8 | Unknown | Henüz çözülmedi |
| 9 | Unknown | Henüz çözülmedi |
| 10 | Unknown | Henüz çözülmedi |
| 11 | Checksum_L | Paket checksum |
| 12 | Checksum_H | Paket checksum |
| 13 | Packet End | 0xFC |

---

#### 2️⃣ Bataryadan Süpürgeye Gönderilen Paket (0x45 Kaynak ID)

| Byte | Field | Açıklama |
|---|---|---|
| 0 | Packet Start | 0xFC |
| 1 | Source ID | 0x45 |
| 2 | Target ID | 0x41 |
| 3 | Charger Status | 3. bit (0: Çıkarıldı, 1: Takıldı) |
| 4 | Battery Level | % cinsinden şarj durumu |
| 5 | Unknown | Henüz çözülmedi |
| 6 | Unknown | Henüz çözülmedi |
| 7 | Checksum_L | Paket checksum |
| 8 | Checksum_H | Paket checksum |
| 9 | Packet End | 0xFB |

---

#### 3️⃣ Bataryadan Süpürgeye Gönderilen Paket (0x42 Kaynak ID)

| Byte | Field | Açıklama |
|---|---|---|
| 0 | Packet Start | 0xFC |
| 1 | Source ID | 0x42 |
| 2 | Target ID | 0x41 |
| 3 | Power_L | Watt cinsinden güç tüketimi (16-bit) |
| 4 | Power_H | Watt cinsinden güç tüketimi (16-bit) |
| 5 | Current_L | Akım verisi (16-bit, birim tahmini) |
| 6 | Current_H | Akım verisi (16-bit, birim tahmini) |
| 7 | Motor Active Flag | 1: Motor çalışıyor, 0: Motor durdu |
| 8 | Unknown | Henüz çözülmedi |
| 9 | Unknown | Henüz çözülmedi |
| 10 | Checksum_L | Paket checksum |
| 11 | Checksum_H | Paket checksum |
| 12 | Packet End | 0xFB |

### Anlamlandırılan Byte Oranı (Payload Coverage)

| Paket | Toplam Byte | Analiz Edilen Byte | Coverage |
|---|---|---|---|
| 0x41  | 14 | 10 | 71% |
| 0x45  | 10 | 8 | 80% |
| 0x42  | 13 | 11 | 85% |
| **Toplam** | 37 | 29 | **~78%** |

> Çözülemeyen byte’lar ya sabit/padding alanlarıdır ya da henüz aktif olmayan protokol field’larıdır.
> Elde edilen veriler, batarya emulasyonunu yapıp süpürgeyi tüm fonksiyonları ile çalıştırmaya yeterlidir.

<details>
<summary><strong>4️⃣ Protokol Emülasyonu</strong></summary>

Protokol emülasyonu aşamasında, mikroişlemci olarak **ESP32** tercih edilmiştir. ESP32, kolay erişilebilirliği, geliştirme ortamının rahatlığı ve entegre Wi-Fi özelliği sayesinde projeyi ileri IoT senaryolarına hazırlamak için ideal bir platform sağlar.  

Daha önce lojik analizör bağlantısı için hazırlanan ve kullanılan **logic level shifter**, ESP32’nin UART bağlantısı için tekrar kullanılmıştır. Single-wire UART yapısında hem RX hem de TX aynı hat üzerinden geçtiği için yalnızca **GPIO16** üzerinden bağlantı yeterli olmuştur.  

Yazılım tarafında bir **haberleşme arayüzü sınıfı (communication interface class)** geliştirilmiştir. Bu class:

- Tek hatlı UART portu dinleme modunda RX, yazma modunda TX yönüne geçirir.
- Dinleme modundayken master’dan (süpürgeden) gelen her paketteki **Target ID**’ye göre uygun yanıtı **data buffer**’ından alır.
- TX moduna geçerek protokolü kesintisiz işletir.
- `begin()` fonksiyonu çağrıldığında kendi **FreeRTOS iş parçacığını (thread)** başlatır ve bu iş parçacığındaki döngüde protokol sürekli olarak çalışır.

Testler için:

- **GPIO33** ADC giriş → Batarya voltajı alanı simülasyonu
- **GPIO26** dijital giriş → Charger status alanı simülasyonu  

Bu yapı sayesinde uygulama katmanında yalnızca **communication interface**’i başlatmak ve **data buffer**’daki ilgili byte’ları okumak veya yazmak yeterlidir.  

Firmware'e erişim için [buraya tıklayabilirsiniz](SOFTWARE/G11_Battery_Controller).

Haberleşme arayüzünün testlerini yapıp doğruladıktan sonra, uygulama katmanında ilk olarak **Battery Level** alanını sürekli olarak artıran ve 100’ü geçtiğinde tekrar 0’a döndüren bir test yazılmıştır. Bu test ile emülasyon denemelerine başlanmıştır ve **ilk denemede protokol başarıyla taklit edilmiştir**.  

Battery Level Test GIF

İkinci aşama olarak, daha önce tanımlanan **ADC girişi (GPIO33)** üzerinden bağlanan potansiyometre ile **Battery Level** ve **dijital giriş (GPIO26)** üzerinden **Charger Status** alanları manipüle edilmiştir. Bu sayede batarya durumu pot ile kontrol edilirken, şarj aleti durumu dijital giriş ile değiştirilmiştir. Yapılan testler de başarılı sonuç vermiştir.  

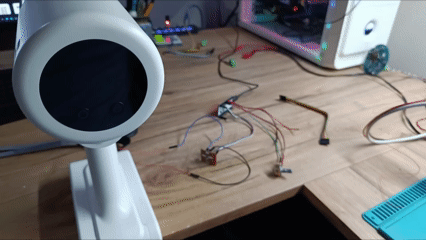
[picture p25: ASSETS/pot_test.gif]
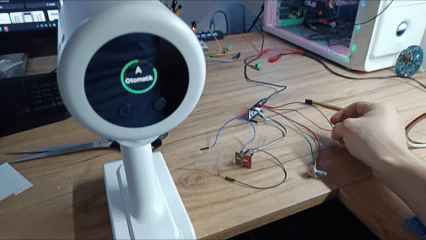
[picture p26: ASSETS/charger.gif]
 

Süpürgeden gelen veriler hâlihazırda alınabildiği için, yazılım geliştirme açısından yeterli altyapıyı sağladığımı düşündüğümden yazılımı bu seviyede bırakıyorum.  
Gerekli **BMS devresi** ve diğer çevre birimler eklendiğinde, orijinal bataryayı tam anlamıyla taklit edebilecek bir emülasyon altyapısı sağlanmış olacaktır.

</details>

<details>
<summary><strong>5️⃣ Donanım Arayüz Tasarımı</strong></summary>

Şimdi yedek batarya üretimi yolundaki bir sonraki aşamaya geçerek donanım tasarımının temellerini atacağız.  

Orijinal batarya daha önce bahsettiğimiz **UI+ / UI- pinlerinde**, normal durumda gerilim sağlamaz. Süpürge **tetik basılıp KEY sinyali gönderildiğinde**, belirli bir zaman aşımı süresince **UI beslemesini açar** ve besleme alındığında haberleşmeyi başlatır. Herhangi bir aktivite olmazsa güç tasarrufu için besleme kesilir. Bu nedenle UI hatlarını doğrudan 24V’a bağlayamayız.  

Buna çözüm olarak, **UI hatlarını anahtarlayan bir anahtarlama devresi** oluşturuldu ve ESP32 I/O pinlerine bağlandı.  
Ek güvenlik amacıyla **sistem genel gücünün de anahtarlanabilmesi** için ayrı bir anahtarlama devresi ile MCU beslemesinde bir **DC-DC düşürücü (buck) dönüştürücü** kullanıldı. Bu düzenlemeler **şematiğin power sayfasında** gösterilmektedir. 

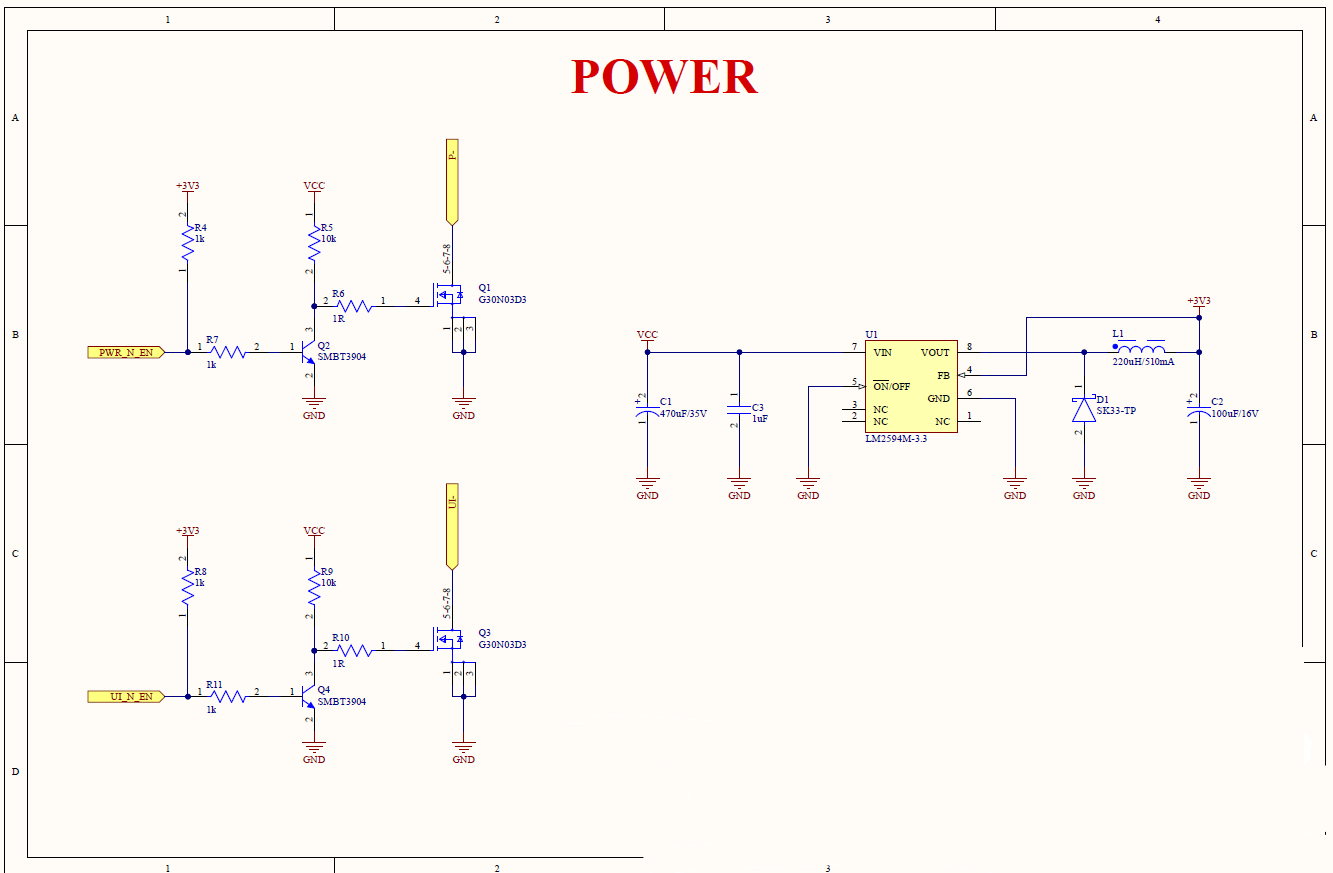
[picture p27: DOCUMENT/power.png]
 

Ayrıca MCU'nun batarya seviyesini anlık ölçüp süpürgeye bildirebilmesi için **5S seri batarya voltajı, 0–3.3V aralığına ölçekleyen bir gerilim bölücü** üzerinden ADC girişine bağlandı. Böylece batarya voltajı ölçülebilmektedir.  

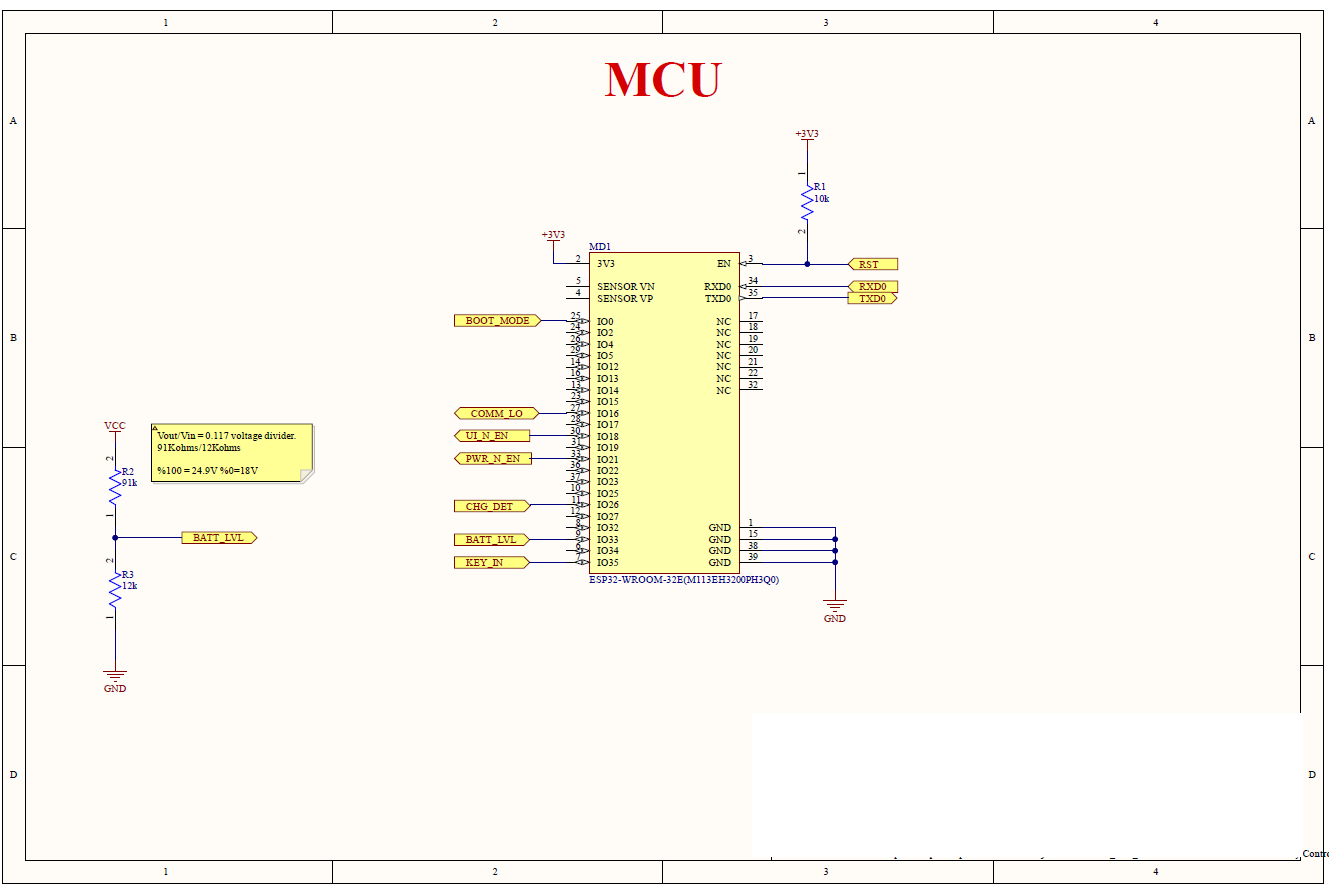
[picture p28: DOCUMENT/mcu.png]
 

Testlerde kullanılan **çift yönlü seviye dönüştürücü (bidirectional level shifter)** yapısı da aynı şekilde şematiğe dahil edilmiştir.  

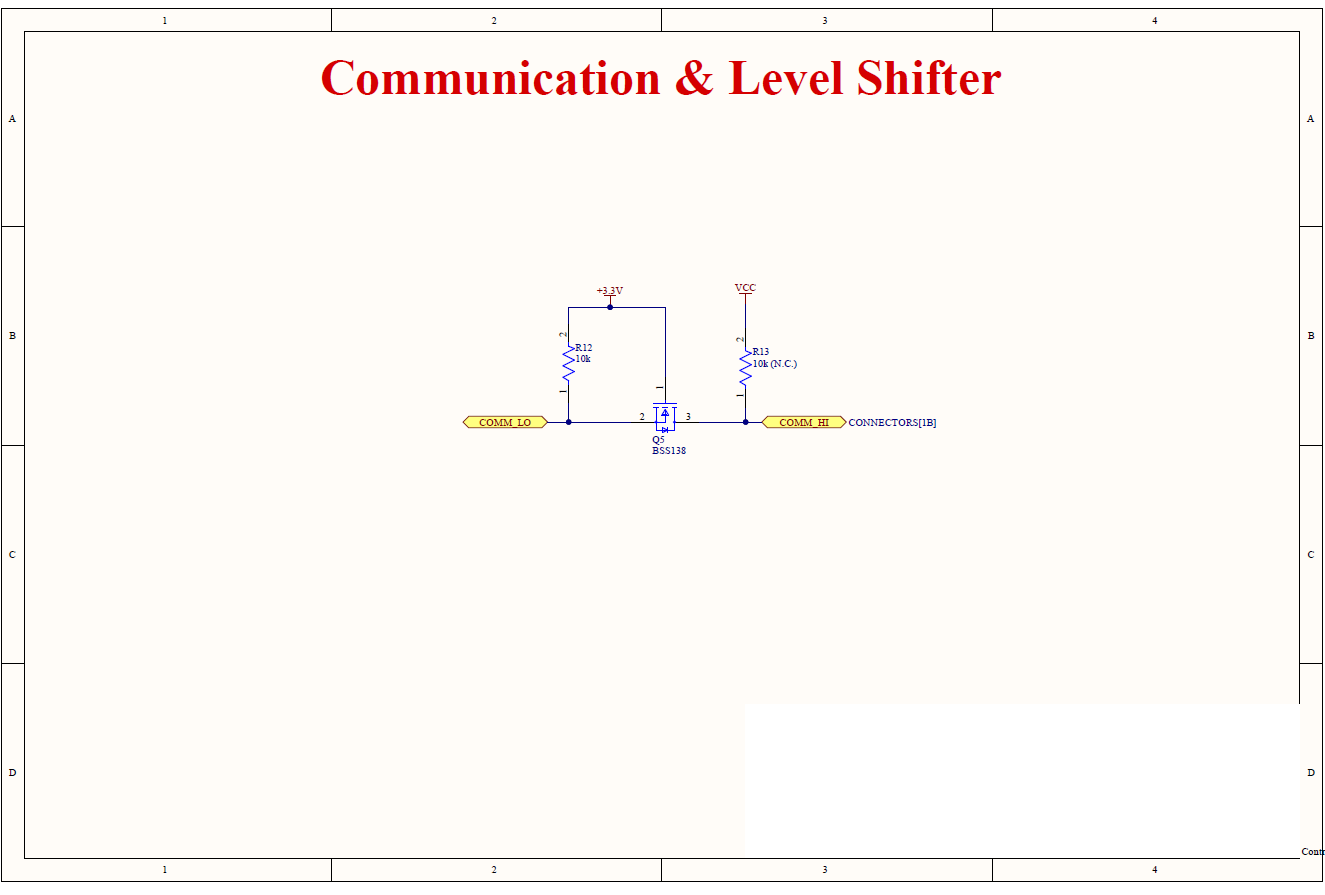
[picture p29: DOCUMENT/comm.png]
 

Şarj aleti bağlantısını tespit etmek için şarj girişi yine bir **gerilim bölücü** üzerinden dijital IO’ya bağlandı.  

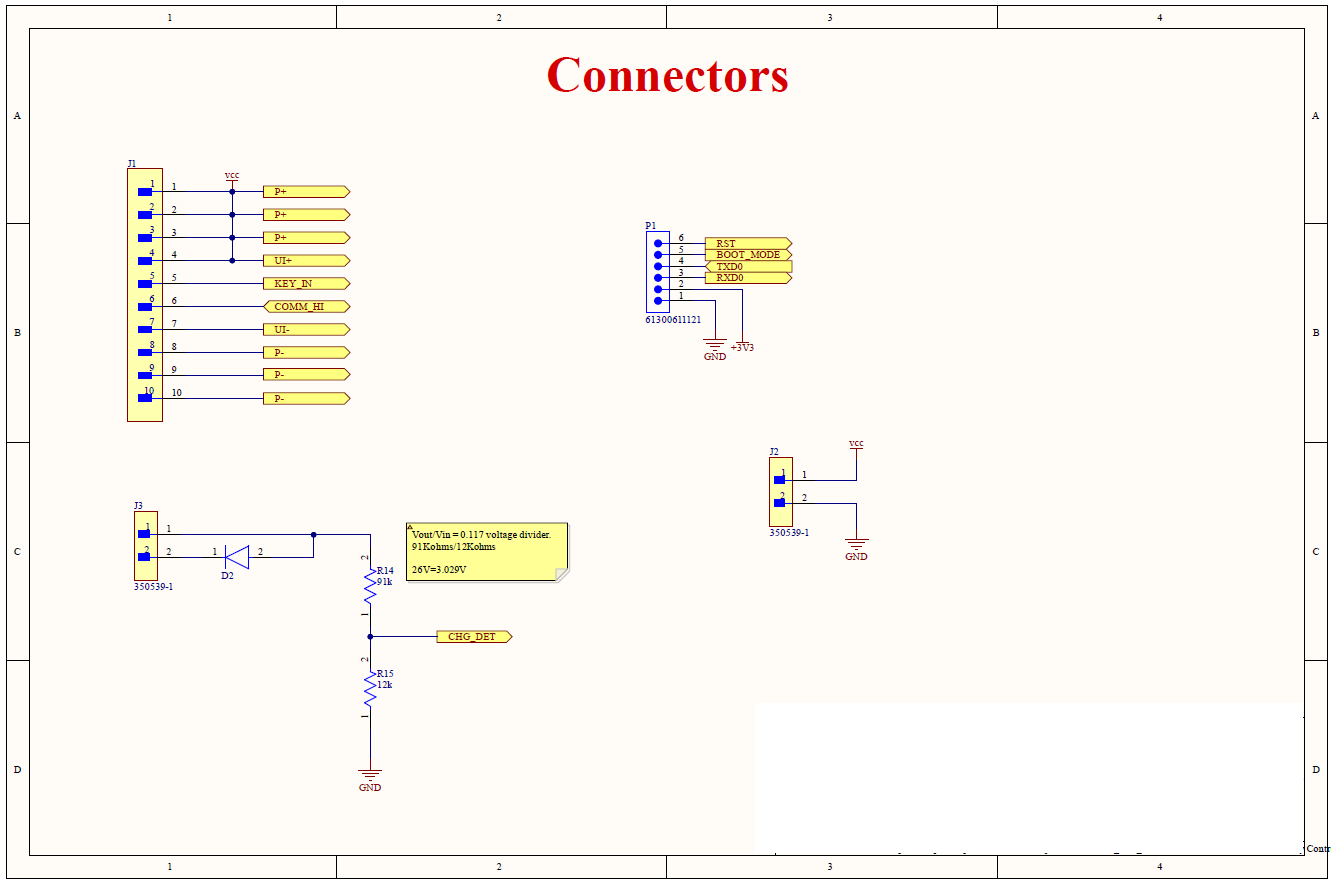
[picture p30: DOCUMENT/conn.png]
 

Bu düzenlemeler, sadece orijinal bataryanın tüm fonksiyonlarını sağlamış olmakla kalmaz, aynı zamanda **Wi-Fi özelliği kazandırarak** bataryayı ileri IoT özellikli bir cihaza dönüştürür.
Tüm şematik ve PCB projesine [buradan](HARDWARE/G11%20Battery%20Controller) erişebilirsiniz.
</details>
<details>
<summary><strong>🎁 Bonus: Batarya Kasa 3D Tasarımı</strong></summary>

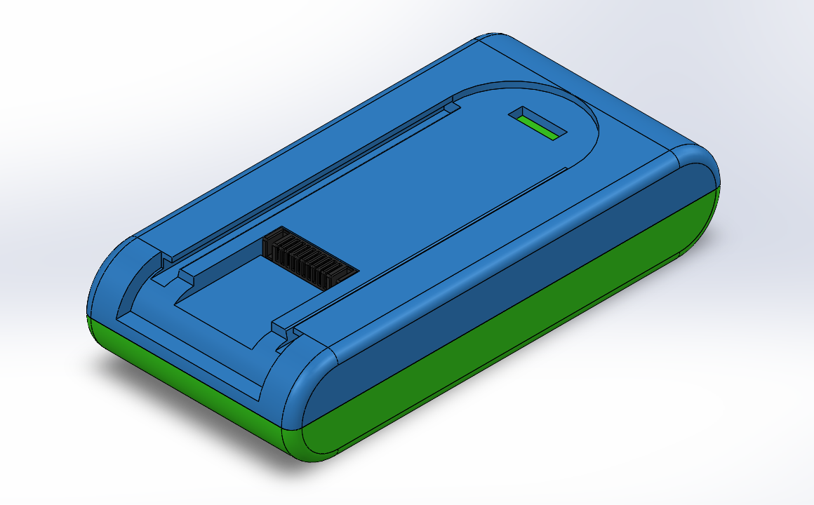
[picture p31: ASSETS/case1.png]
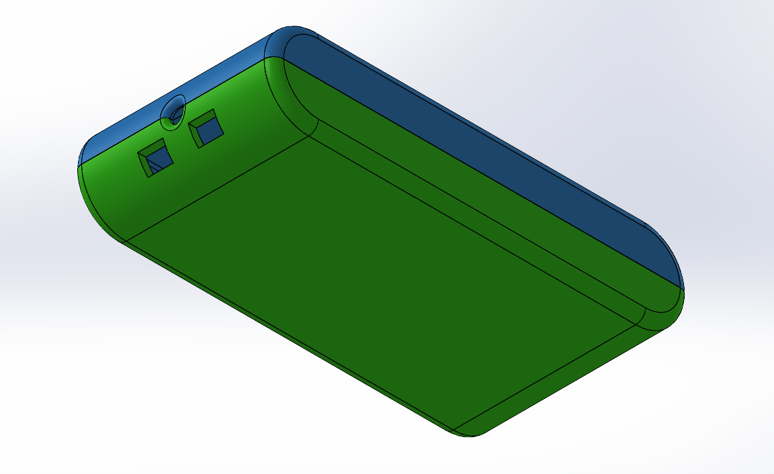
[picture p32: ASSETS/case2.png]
 

Bataryanın fiziksel kutusunun 3D tasarım dosyaları [buraya](3D/g11%20battery%20case) bakabilirsiniz.

</details>

## Repository Yapısı

| Dizin | İçerik |
|---|---|
| `ASSETS/` | Fotoğraflar, grafikler, test görselleri ve GIF'ler |
| `DOCUMENT/` | Logic analyzer kayıtları, Excel protokol analizi ve şema görselleri |
| `SOFTWARE/` | ESP32 protokol emülatörü |
| `HARDWARE/` | Batarya denetleyici şematik ve PCB projesi |
| `3D/` | Batarya kutusu tasarım dosyaları |

## Proje Durumu

Bu çalışma **tamamlanmış bir reverse-engineering ve proof-of-concept emülasyon projesidir**.

- Reverse engineering: **Tamamlandı**
- Protokol emülasyonu: **Tamamlandı**
- Donanım tasarımı: **Tamamlandı**
- Firmware proof of concept: **Tamamlandı**
- Yeni protokol analizi: **Planlanmıyor**

Bazı payload byte'ları test sırasında değişmediği veya gösterilen emülasyon için gerekli olmadığı için tanımlanmamıştır. Projenin hedeflediği işlevsel emülasyon mevcut veri ve uygulama ile doğrulanmıştır.

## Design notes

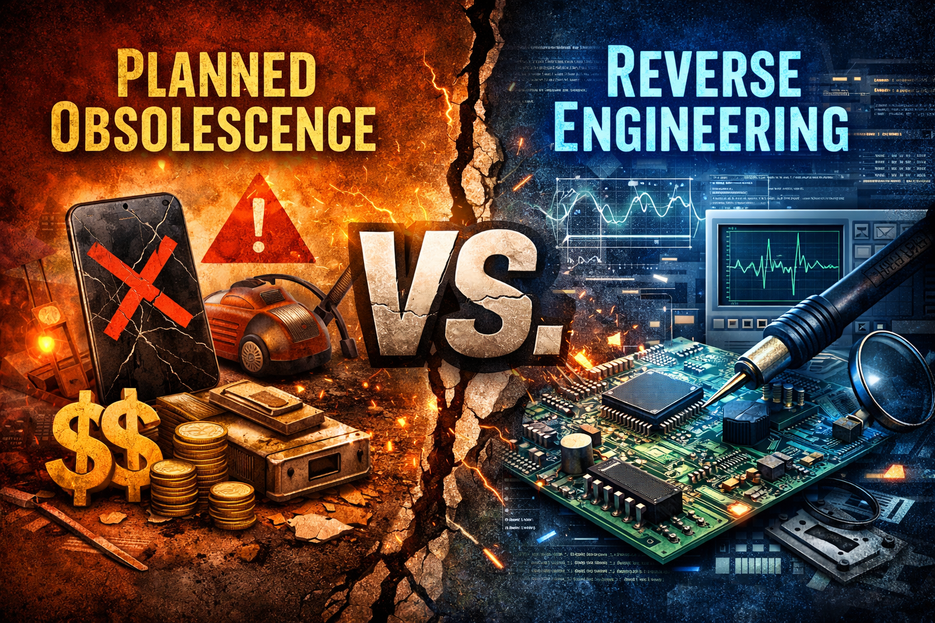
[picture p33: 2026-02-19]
ASSETS/cover.png

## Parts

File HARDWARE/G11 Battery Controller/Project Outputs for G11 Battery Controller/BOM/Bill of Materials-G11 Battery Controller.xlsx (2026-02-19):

Name | Designator | Case/Package | LCSC Part #
SK33-TP | D1 | SMC | C151786
LM2594M-3.3 | U1 |  | C3029048
ESP32-WROOM-32E(M113EH3200PH3Q0) | MD1 |  | C701341
61300611121 | P1
470uF/35V | C1 | Radial | C280413
220uH/510mA | L1 |  | C2929444
100uF/16V | C3 | Molded | C122646
91k | R1 | 603
12k | R2 | 603
10k | R3 | 603
1uF | C2 | 0603 | C478859

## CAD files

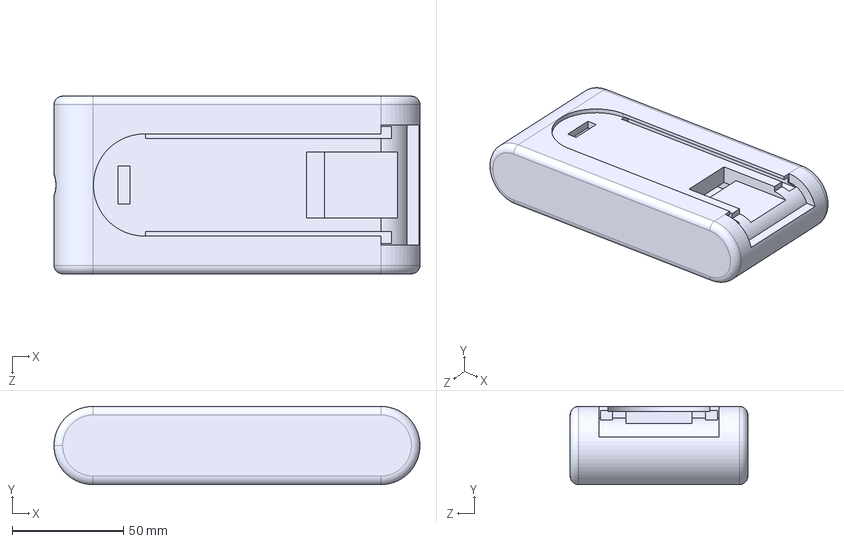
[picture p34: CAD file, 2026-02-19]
3D/g11 battery case/full model.STEP
164.8 x 35.2 x 80.0 mm

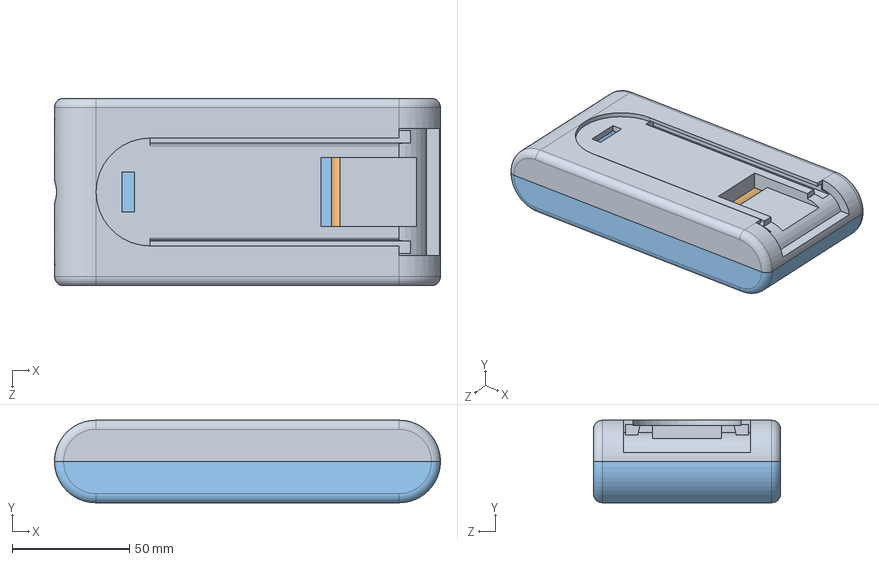
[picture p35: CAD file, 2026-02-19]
3D/g11 battery case/Montaj.SLDASM
164.8 x 35.3 x 80.0 mm
bott model
18650_battery x 6
top model

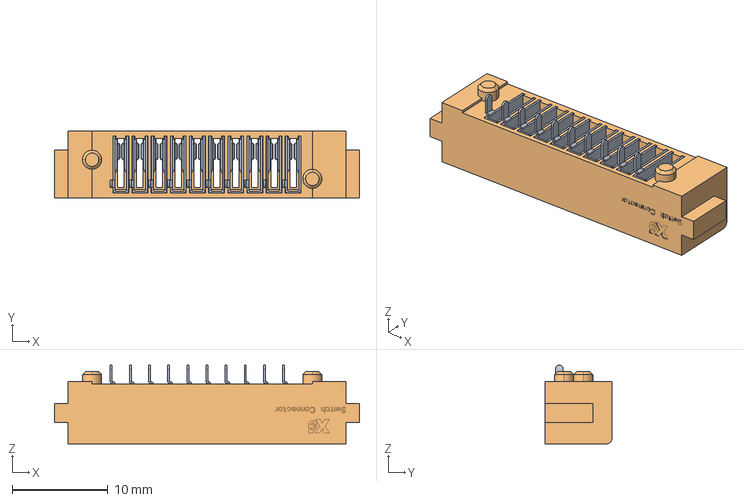
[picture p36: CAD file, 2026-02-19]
3D/g11 battery case/10p.stp
31.9 x 7.00 x 8.25 mm

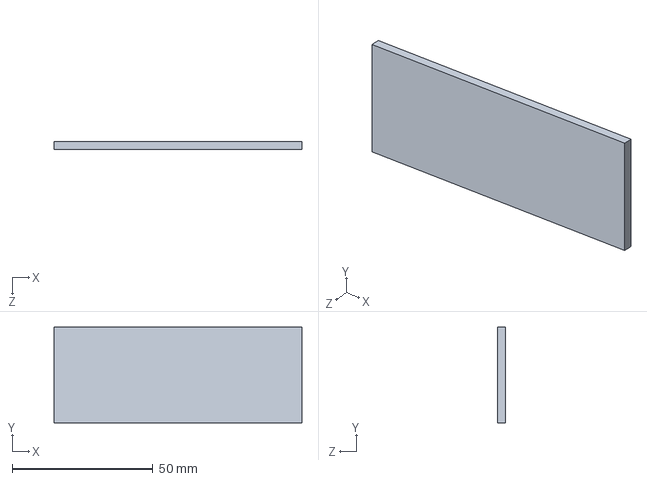
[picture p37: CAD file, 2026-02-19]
3D/g11 battery case/bms.SLDPRT
88.0 x 34.0 x 2.80 mm

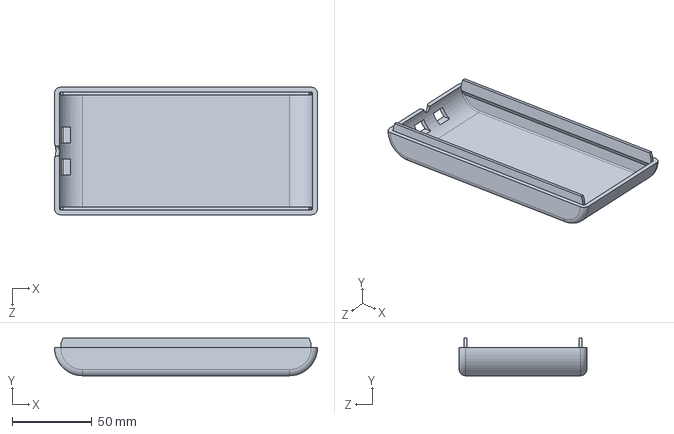
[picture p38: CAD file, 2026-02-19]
3D/g11 battery case/bott model.SLDPRT
164.8 x 23.5 x 80.0 mm

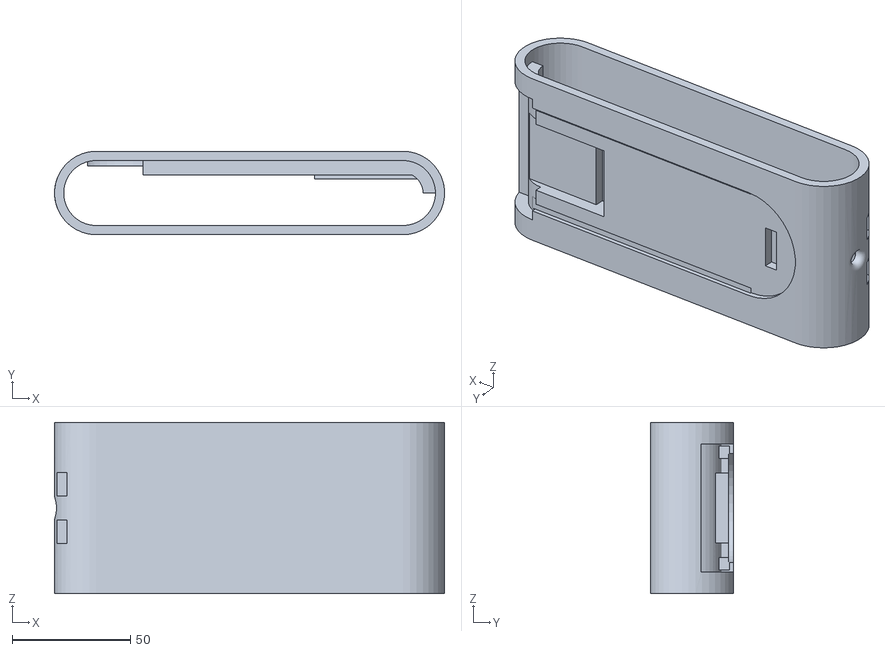
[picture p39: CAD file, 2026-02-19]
3D/g11 battery case/orta.STL
164.7 x 35.2 x 72.2

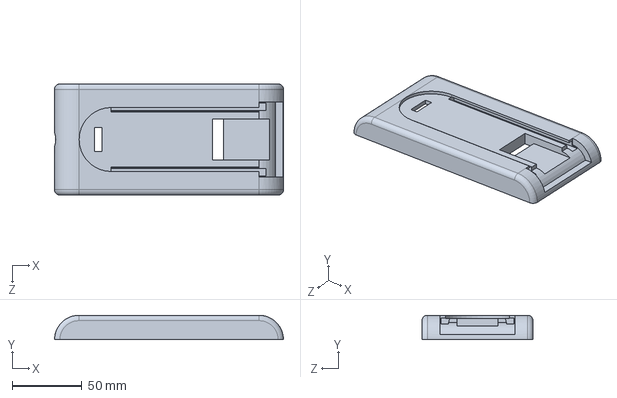
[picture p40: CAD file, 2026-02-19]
3D/g11 battery case/top model.SLDPRT
164.8 x 17.6 x 80.0 mm

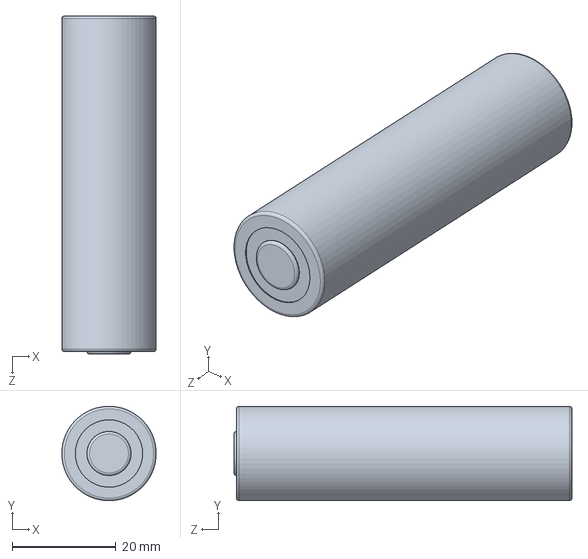
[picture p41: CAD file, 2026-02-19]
3D/g11 battery case/18650_battery.SLDPRT
18.2 x 18.2 x 65.2 mm

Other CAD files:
3D/g11 battery case/yan.STL
3D/g11 battery case/bott model.STL
3D/g11 battery case/full model.SLDPRT
3D/g11 battery case/top model.STL

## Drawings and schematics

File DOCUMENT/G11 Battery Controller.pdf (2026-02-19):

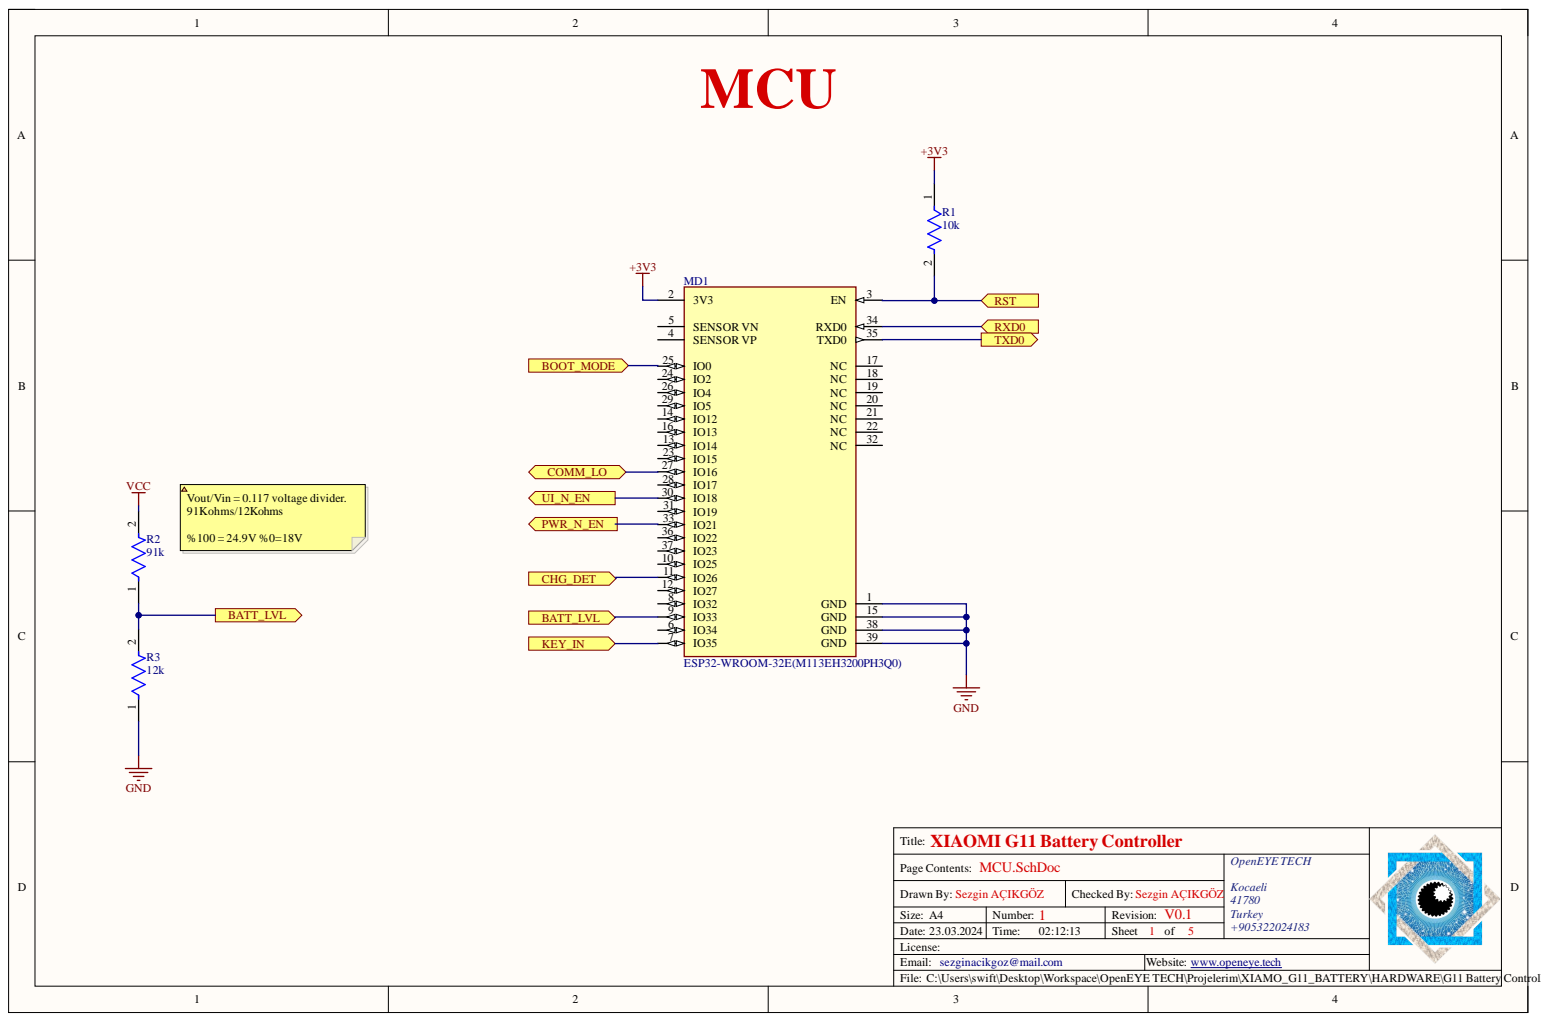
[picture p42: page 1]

Page Co n ten t s : MCU.S c h D o c | Open EYE TECH Koca e l i 4 1 78 0 Tu rkey +9 0 5 3 2 2 02 4 1 8 3

Draw n By : Sezg i n A ÇIK G Ö Z | Checked By : Sezg i n A ÇIK G Ö Z
Size : A 4 | 1 N umb er : | V0 . 1 Rev i s i o n :
Dat e : 2 3.0 3 . 2 0 2 4 | T ime : 0 2 : 1 2 : 1 3 | Shee t 1 o f 5

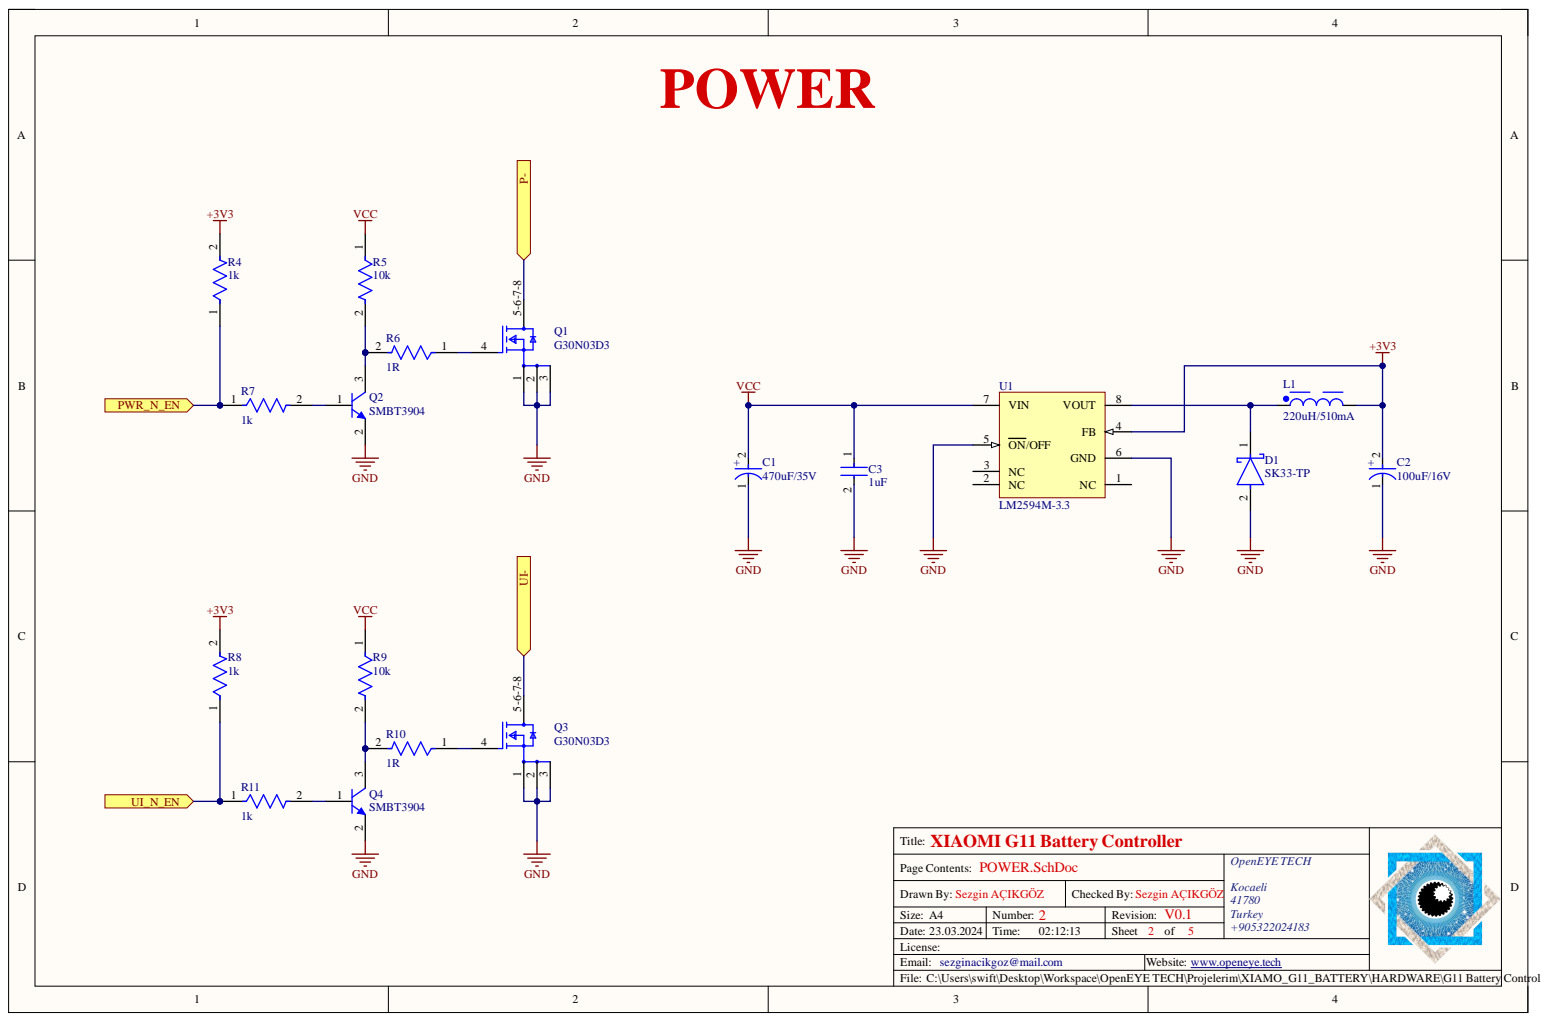
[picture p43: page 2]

Page Co n ten t s : POWER.S c h D o c | Open EYE TECH Koca e l i 4 1 78 0 Tu rkey +9 0 5 3 2 2 02 4 1 8 3

Draw n By : Sezg i n A ÇIK G Ö Z | Checked By : Sezg i n A ÇIK G Ö Z
Size : A 4 | 2 N umb er : | V0 . 1 Rev i s i o n :
Dat e : 2 3.0 3 . 2 0 2 4 | T ime : 0 2 : 1 2 : 1 3 | Shee t 2 o f 5

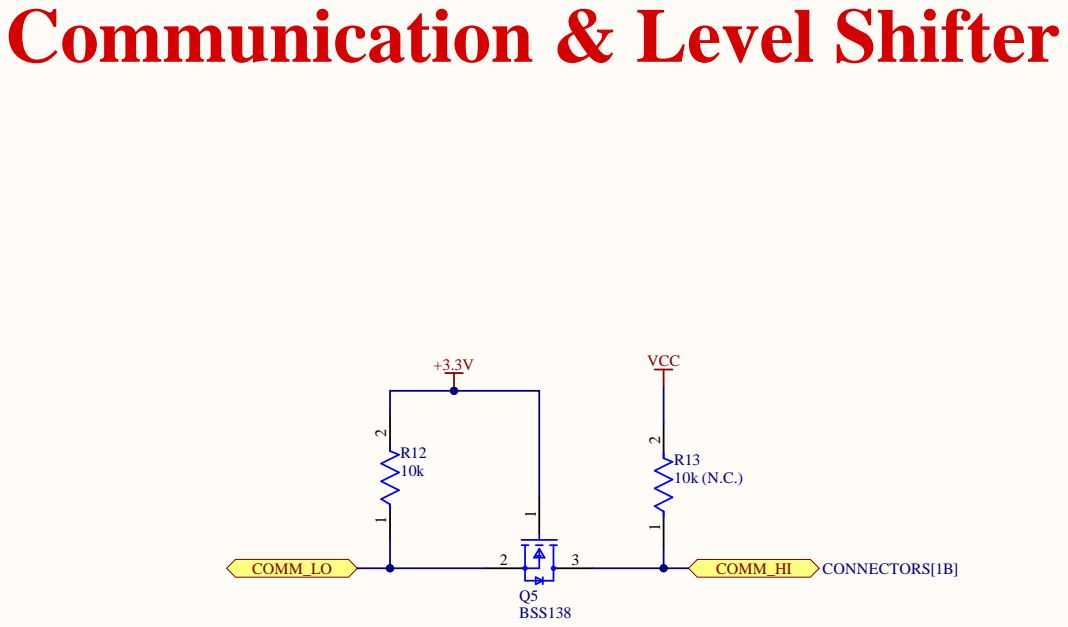
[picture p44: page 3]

Page Contents: COMMLEVELSHIFTER.SchDoc | OpenEYE TECH Kocaeli 41780 Turkey +905322024183

Drawn By: Sezgin AÇIKGÖZ | Checked By: Sezgin AÇIKGÖZ
Size: A4 | 3 Number: | V0.1 Revision:
Date: 23.03.2024 | Time: 02:12:13 | Sheet 3 of 5

License:
Email:
C:\Users\swift\Desktop\Workspace\OpenEYE TECH\Projelerim\XIAMO_G11_BATTERY\HARDWARE\G11 Battery Controller\COMM LEVELSHIFTER.SchDoc

Website: www.openeye.tech

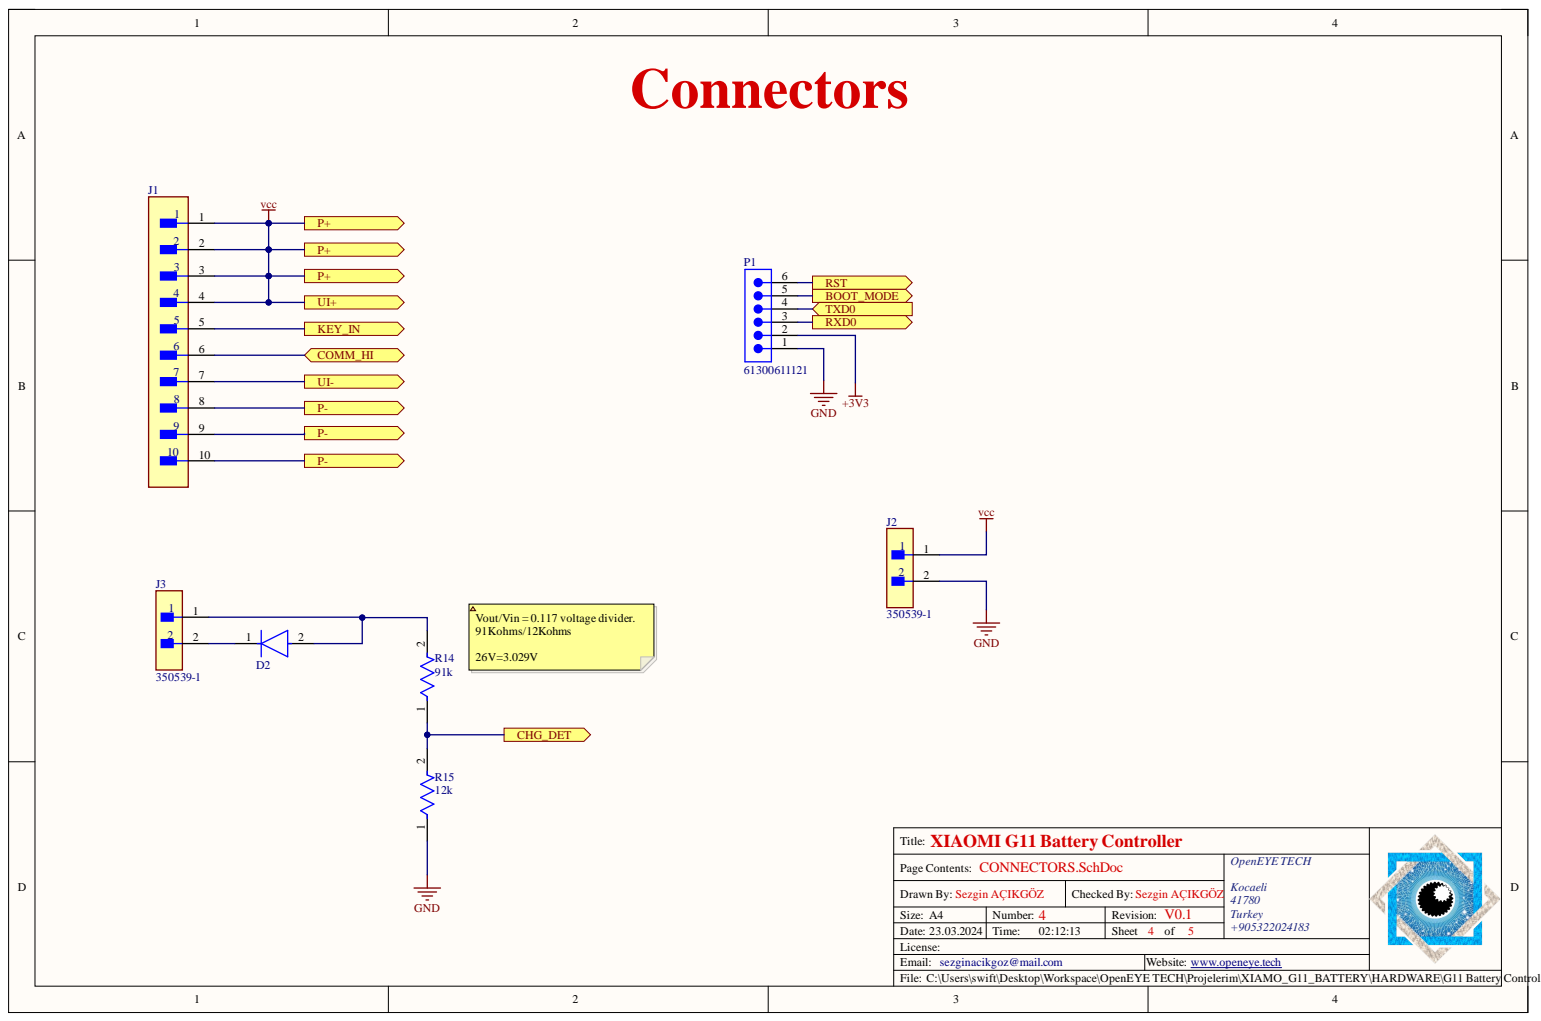
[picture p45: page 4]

Vout/Vin = 0.117 voltage divider.
91Kohms/12Kohms

Page Contents: CONNECTORS.SchDoc | OpenEYE TECH Kocaeli 41780 Turkey +905322024183

Drawn By: Sezgin AÇIKGÖZ | Checked By: Sezgin AÇIKGÖZ
Size: A4 | 4 Number: | V0.1 Revision:
Date: 23.03.2024 | Time: 02:12:13 | Sheet 4 of 5

License:
Email:
C:\Users\swift\Desktop\Workspace\OpenEYE TECH\Projelerim\XIAMO_G11_BATTERY\HARDWARE\G11 Battery Controller\CONNECTORS.SchDoc

Website: www.openeye.tech

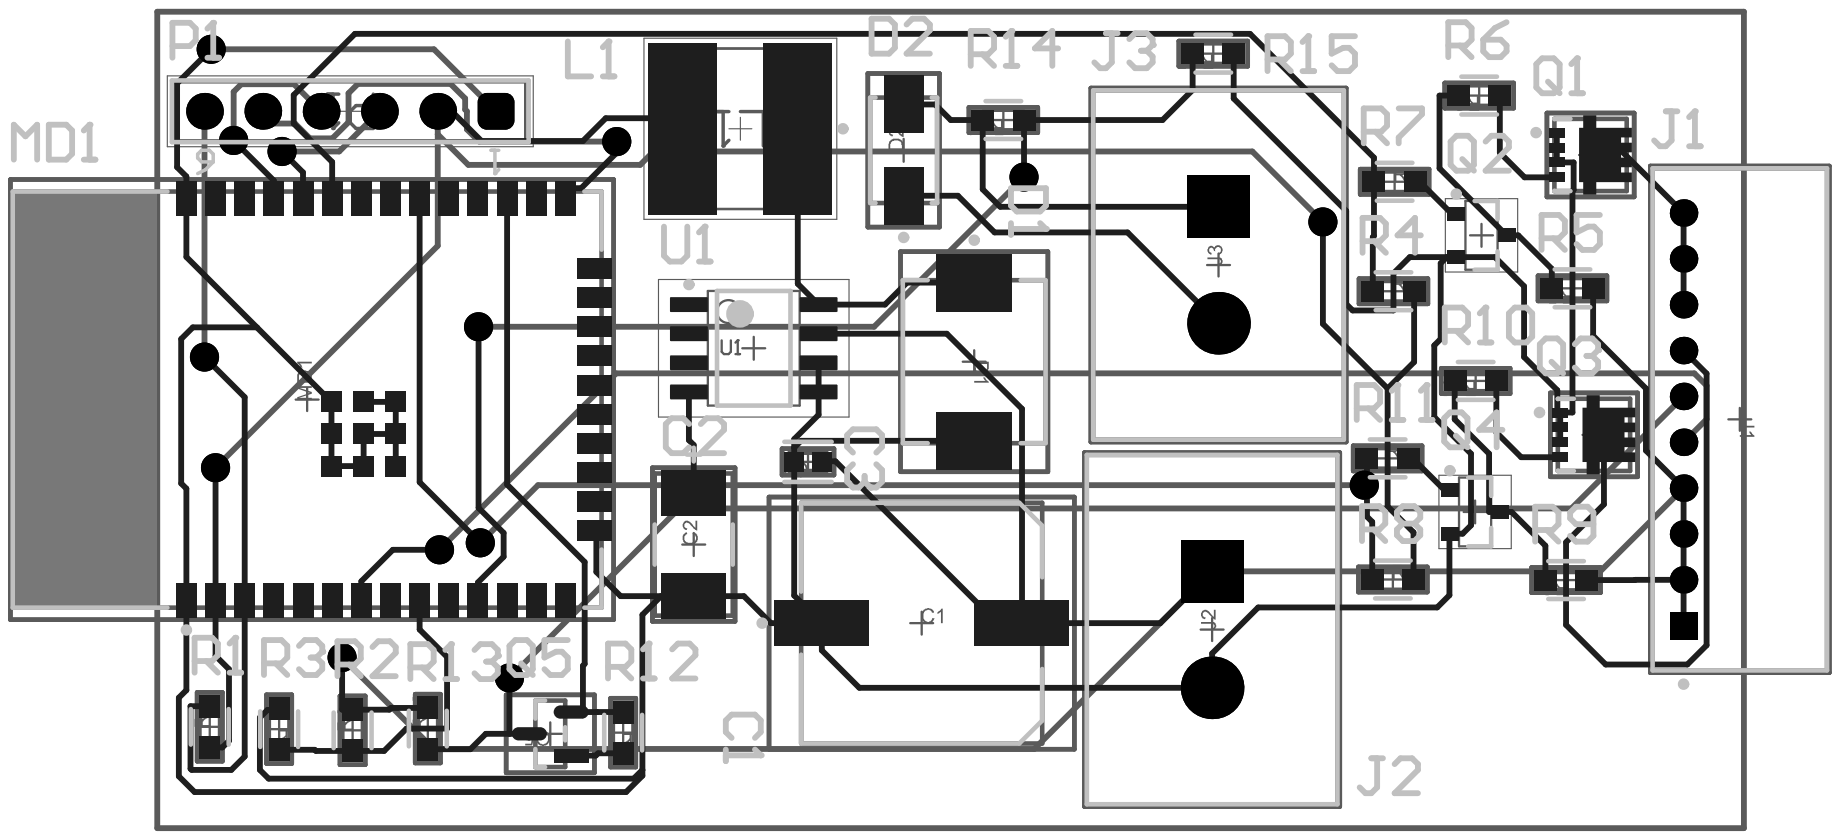
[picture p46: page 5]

Comment | Designator | Case/Package | LCSC Part #
SMBT3904 | Q2 | | C896900
SMBT3904 | Q4 | | C896900
SK33-TP | D1 | SMC | C151786
S10B-PH-K-S(LF)(SN) | J1
LM2594M-3.3 | U1 | | C3029048
G30N03D3 | Q1 | | C840054
G30N03D3 | Q3 | | C840054
ESP32-WROOM-32E(M113EH3200PH3Q0) | MD1 | | C701341
ES2DA-13-F | D2 | | C5140013
BSS138 | Q5 | SOT-23 | C5224260
61300611121 | P1
350539-1 | J2
350539-1 | J3
470uF/35V | C1 | Radial | C280413
220uH/510mA | L1 | | C2929444
100uF/16V | C2 | Molded | C122646
91k | R2 | 603
91k | R14 | 603
12k | R3 | 603
12k | R15 | 603
10k (N.C.) | R13 | 603
10k | R1 | 603
10k | R5 | 603
10k | R9 | 603
10k | R12 | 603
1uF | C3 | 0603 | C478859
1R | R6 | 603
1R | R10 | 603
1k | R4 | 603
1k | R7 | 603
1k | R8 | 603
1k | R11 | 603

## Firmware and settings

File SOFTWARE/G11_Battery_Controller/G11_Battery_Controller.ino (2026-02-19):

#define ESP32_RTOS
#include "OTA.h"
#include "comm_interface.h"
void setup() {
  setupOTA(mySSID, mySSID, myPASSWORD);
  CI.init();
  CI.begin();
  pinMode(26, INPUT_PULLUP);
  pinMode(32, OUTPUT);
  pinMode(25, OUTPUT);
  pinMode(27, OUTPUT);
  digitalWrite(32, HIGH);
  digitalWrite(25, LOW);
  digitalWrite(27, LOW);
  analogReadResolution(12);
}

void loop() {
  double v_batt = analogReadMilliVolts(33) * 8.547008547008547;  // Vout/Vin = 0.117 voltage divider. 91Kohms/12Kohms
  uint8_t batt_percentage = map(v_batt, 18000, 24900, 0, 100);   // %100 = 24.9V %0=18V
  if (batt_percentage > 100) batt_percentage = 100;
  if (batt_percentage < 0) batt_percentage = 0;

  CI.TXPacket0x45.s.batt_lvl = batt_percentage;
  bool charger_status = digitalRead(26);
  bitWrite(CI.TXPacket0x45.s.io_stat, 0, charger_status);
  bitWrite(CI.TXPacket0x45.s.io_stat, 1, charger_status);
  bitWrite(CI.TXPacket0x45.s.io_stat, 2, !charger_status);
  delay(250);

  Serial.print("Charger Status: ");
  Serial.print(charger_status);
  Serial.print(" - Battery Status: ");
  Serial.println(CI.TXPacket0x45.s.batt_lvl);
}
void Received_event() {
}

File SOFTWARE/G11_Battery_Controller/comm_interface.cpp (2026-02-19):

#include "comm_interface.h"
CommInterface CI;
void CommInterface::init() {
  Serial.begin(115200);
  Serial2.begin(9600, SERIAL_8N1, RXD2, TXD2, true);
  Serial.println("Half-Duplex UART Started");
  TXPacket0x42.s.start = 0xFC;
  TXPacket0x42.s.source_id = 0x42;
  TXPacket0x42.s.target_id = 0x41;
  TXPacket0x42.s.byte7 = 0x01;
  TXPacket0x42.s.end = 0xFB;

  TXPacket0x45.s.start = 0xFC;
  TXPacket0x45.s.source_id = 0x45;
  TXPacket0x45.s.target_id = 0x41;
  TXPacket0x45.s.io_stat = 0x43;
  TXPacket0x45.s.batt_lvl = 0x64;
  TXPacket0x45.s.byte5 = 0x64;
  TXPacket0x45.s.byte6 = 0x00;
  TXPacket0x45.s.end = 0xFB;
}
void CommInterface::begin() {
  xTaskCreate(
    receive_thread,
    "RECEIVE_THREAD",
    10000,
    this,
    1,
    NULL);
}
uint16_t CommInterface::calculateChecksum(uint8_t* buffer) {

  uint16_t checksum = 0;
  if (buffer[1] == 0x41) {
    for (int i = 1; i < 11; i++) {
      checksum += buffer[i];
    }
  } else if (buffer[1] == 0x42) {
    for (int i = 1; i < 8; i++) {
      checksum += buffer[i];
    }
  } else if (buffer[1] == 0x45) {
    for (int i = 1; i < 7; i++) {
      checksum += buffer[i];
    }
  }
  return checksum;
}
void CommInterface::transmit(uint8_t* buffer, size_t size) {
  Serial2.end(true);
  Serial2.begin(9600, SERIAL_8N1, TXD2, RXD2, true);
  // Serial.print("TX:");
  for (int i = 0; i < size; i++) {
    // Serial.print(" ");
    // Serial.print(buffer[i], HEX);
    Serial2.write(buffer[i]);
  }
  // Serial.println();
  Serial2.flush();
  Serial2.end(true);
  Serial2.begin(9600, SERIAL_8N1, RXD2, TXD2, true);
}
void CommInterface::send_response(uint8_t response_type) {
  if (response_type == 0x42) {
    TXPacket0x42.s.checksum = calculateChecksum(TXPacket0x42.b);
    transmit(TXPacket0x42.b, sizeof(TXPacket0x42));
  } else if (response_type == 0x45) {
    TXPacket0x45.s.checksum = calculateChecksum(TXPacket0x45.b);
    transmit(TXPacket0x45.b, sizeof(TXPacket0x45));
  }
}
void CommInterface::receive_thread(void* parameter) {
  CommInterface* taskInstance = (CommInterface*)parameter;
  while (true) {
    if (Serial2.available() > 13) {
      uint8_t x = Serial2.read();
      if (x == 0xFB) {
        taskInstance->RXPacket0x41.b[0] = x;
        x = Serial2.read();
        if (x == 0x41) {
          taskInstance->RXPacket0x41.b[1] = x;
          x = Serial2.read();
          if ((x == 0x42) | (x == 0x43) | (x == 0x44) | (x == 0x45)) {
            taskInstance->RXPacket0x41.b[2] = x;
            for (int i = 3; i < 14; i++) {
              taskInstance->RXPacket0x41.b[i] = Serial2.read();
            }
            if (taskInstance->RXPacket0x41.s.end == 0xFC) {
              if (taskInstance->calculateChecksum(taskInstance->RXPacket0x41.b) == taskInstance->RXPacket0x41.s.checksum) {

                // Serial.print("RX:");
                // for (int i = 0; i < 14; i++) {
                //   Serial.print(" ");
                //   Serial.print(taskInstance->RXPacket0x41.b[i], HEX);
                // }
                // Serial.println();
                taskInstance->send_response(taskInstance->RXPacket0x41.s.target_id);
              } else {
                Serial.println("RX: Checksum Error");
              }
            } else {
              Serial.print("RX: Wrong end!:");
              Serial.println(x, HEX);
            }
          } else {
            Serial.print("RX: Wrong target id!:");
            Serial.println(x, HEX);
          }
        } else {
          Serial.print("RX: Wrong Source id!:");
          Serial.println(x, HEX);
        }
      }
    }
    vTaskDelay(pdMS_TO_TICKS(1));
  }
}

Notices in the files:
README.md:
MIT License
